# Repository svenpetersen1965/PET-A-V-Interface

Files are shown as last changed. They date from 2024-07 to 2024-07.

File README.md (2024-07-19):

# PET-A-V-Interface
And A/V Interface for Commodore PET computers
This is a <b>preliminary release</b>. The electronics is fully functional, but the test documentation might require some tweaking. 

The prupose of this project is providing video and audio (CB2) outputs for the Commodore PET computers. The non-CRTC machines generate video outputs, which can be mixed to resemble an NTSC video signal. The resulting signal can be displayed with NTSC monitors or suitable video to HDMI converters.

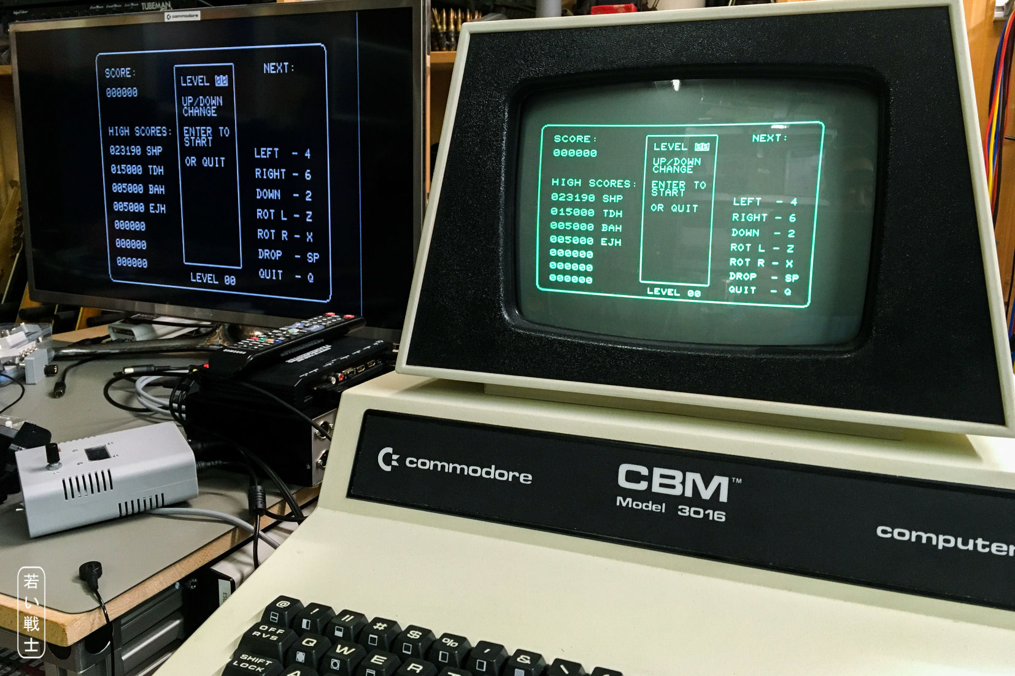
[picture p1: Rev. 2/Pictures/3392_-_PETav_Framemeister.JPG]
CBM3016 with external display


The internal video signal of the CRTC machines is not following any video standards. Thus it requires to modify the CRTC parameters in the EDIT ROM. The disavantage of these modiied settings is, that the internal monitor does not synchronize with them. It is mandatory to disconnect the video and the supply voltage for the monitor if run with PAL or NTSC parameters for more than just a few minutes.

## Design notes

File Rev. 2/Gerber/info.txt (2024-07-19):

      
       Board: PET_AV_Interface
       Rev.:  2
  
       Files:
       ======
  
       All Gerber files are generated in extended gerber format (RS274X)
       *.TOP        : Film top copper
       *.BOT        :  -"- bottom copper
       *.STC        :  -"- top soldermask 
       *.STS        :  -"- bottom soldermask
       *.PLC        :  -"- silk screen top
       *.PLS        :  -"- silk screen bottom 
       *.DK         : Drills plated Through (Excellon)
       *.NDK        : Drills not plated Through (Excellon)
       *.OUT        : Board outline

       Board Size:
       ===========
       Length     :   68.0 mm
       Width      :   56.0 mm
       Thickness  :   1.6 mm
       Material   :   FR 4
       Copper     :   35 um
       Surface    :   HASL
       
       Remarks:
       ========
       Width >= 8mil
       Distance >= 6mil
       Drill >= 0.35mm

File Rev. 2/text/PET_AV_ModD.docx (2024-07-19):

Commodore PET/CBM80xx/40xx A/V-Interface Rev. 2

Module Description

The PET A/V-Interface allows to output composite video and audio signals from the user port of the PET. Non-CRTC machines, like the PET 20xx or CBM30xx are outputting video information, which can be mixed to an NTSC video signal (Figure 5).

CRTC machines, like most CBM40xx and CBM80xx do not follow any video standard, they generate 50 FPS, but the horizontal rates do not fit any video standard. They require a different edit ROM to meet either PAL or NTSC. With this new edit ROM, the built in monitor will not synchronize. It is recommended to switch off the supply voltage of the monitor, while the PAL or NTSC edit ROM is active.

The audio signal is derived from the CB2 output of the User Port, which is widely used to produce audio with PET or CBM machines. The amplitude of the audio signal is approximately 0.6V. The signal is not suitable to directly drive a speaker, an amplifier is required. It is recommended to try out low volume setting first and adjust the volume to taste. Both J7/white and J6/red are identical, since there is no stereo output. It is desirable to connect the audio signal to both stereo channels of the audio/video equipment.

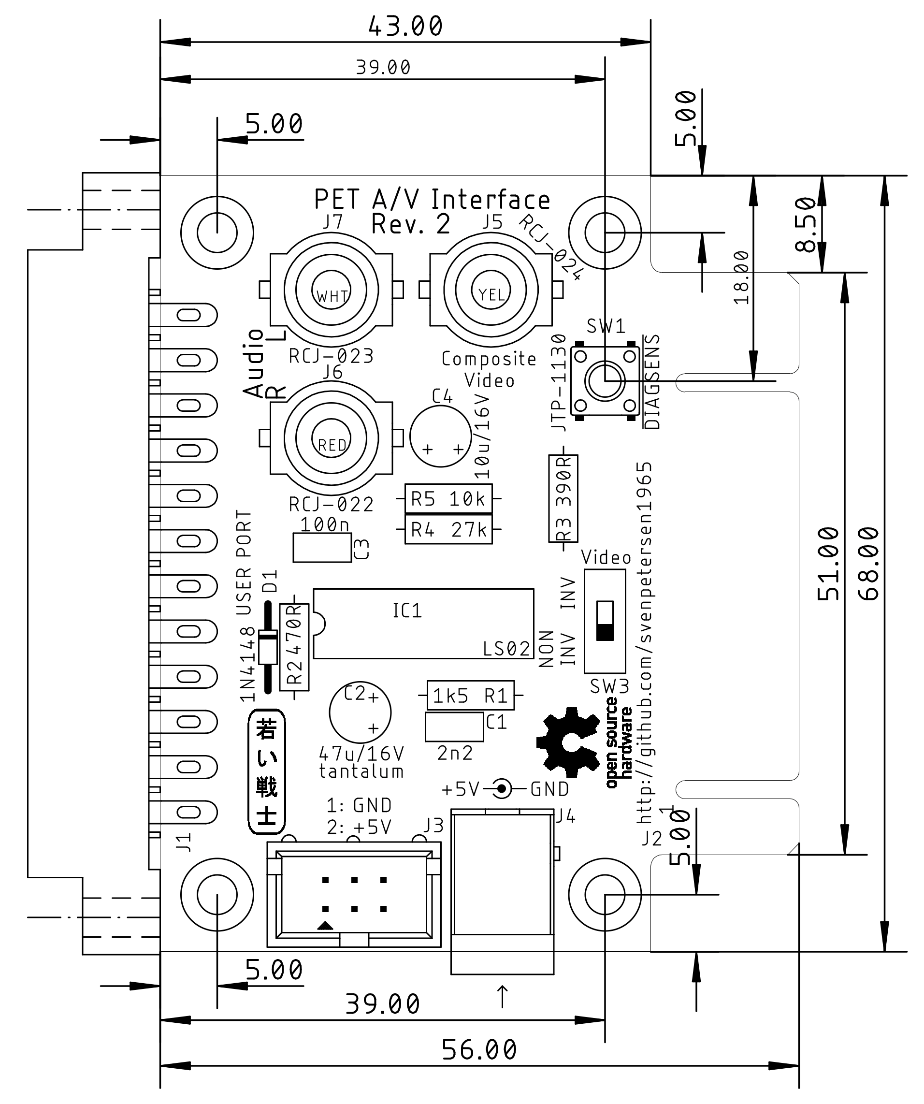
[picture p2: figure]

Figure 1: Dimensions of the PET A/V Interface

The A/V Interface requires a supply voltage of 5V, since the PET user port does not have a +5V pin (like the C64 user port). There are two ways to get 5V to the circuit:

1. Tap the Cassette Port with the Cassette Port dongle of the C64 Diagnostic Harness (which is pass through), a Datassette can still be used.
2. A 5V power supply with a 5.5mm/2.5mm barrel jack (inner lead is +5V).

The User Port of the PET is passed through and can be fully used on the edge connector of the board.

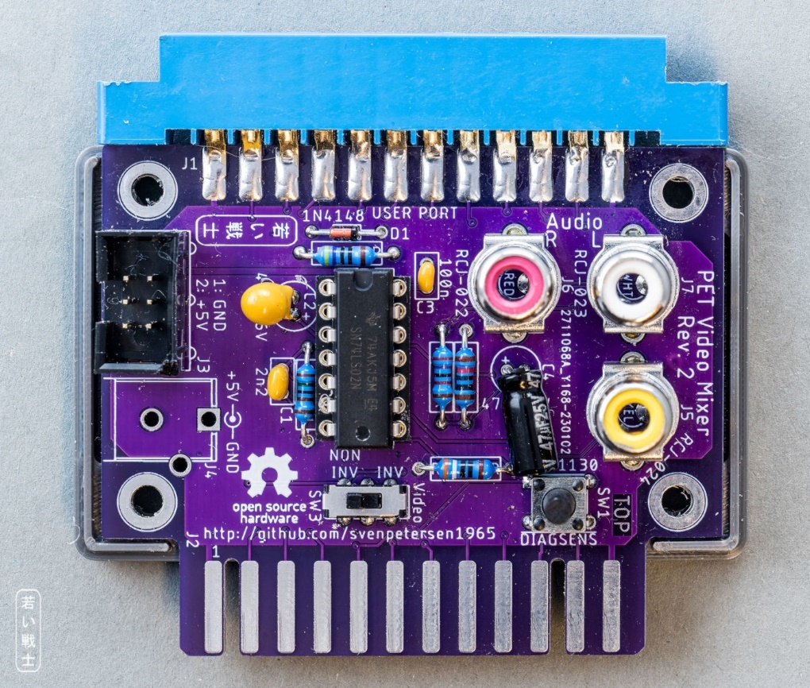
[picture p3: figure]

Figure 2: PET A/V Interface Rev. 2 with power via cassette port/box connector (J3)

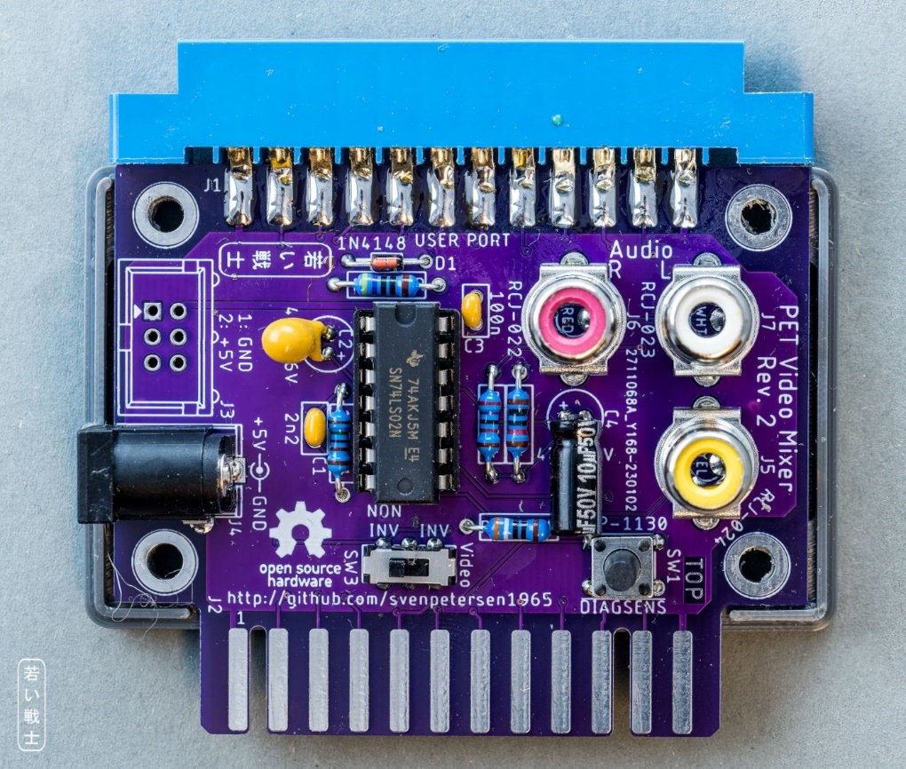
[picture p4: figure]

Figure 3: PET A/V Interface Rev. 2 with barrel connector (J4)

Note: C2 has to be a tantalum capacitor

Note: C4 has to be put flat to fit into the 3D printed case (Figure 2, Figure 3)

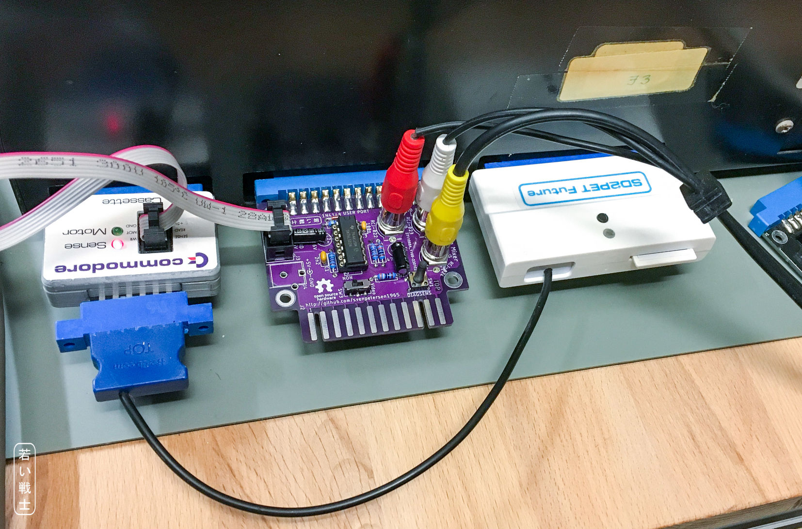
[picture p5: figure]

Figure 4: PET A/V Interface on CBM3016, powered from Cassette port (and SD2PET Future Floppy Disk emulator)


Figure 5: CBM3016 monitor and video output on a Framemeister HDMI adapter

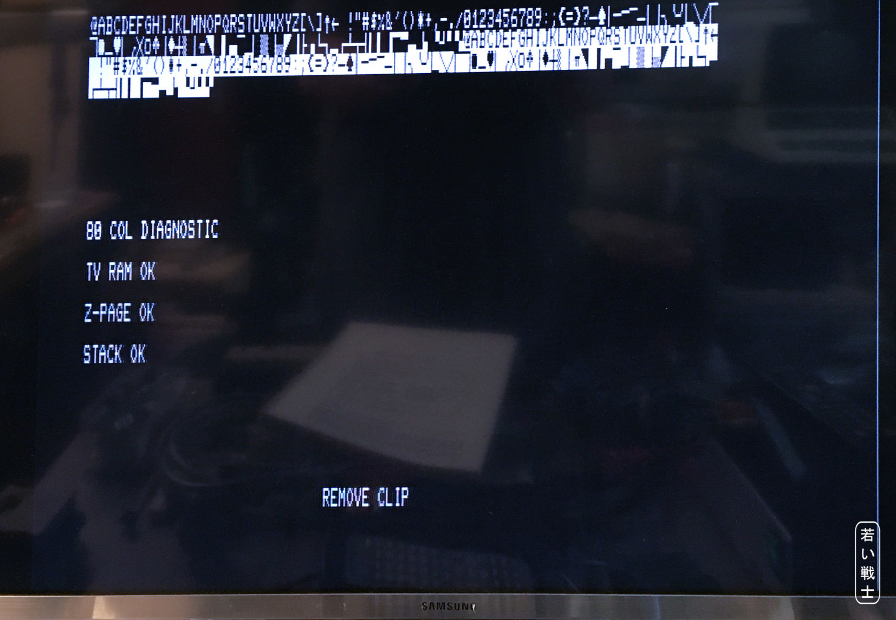
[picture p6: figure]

Figure 6: Output of a CRTC machine with edited parameters for NTSC output (the diagnostic clip software)

The CRTC parameters for an NTSC (60Hz) output were derived from Steve Gray’s Edit ROM (https://github.com/sjgray/cbm-edit-rom/blob/master/crtc-reg-normal.asm) project: https://github.com/sjgray/cbm-edit-rom/blob/master/crtc-reg-normal.asm

Note: It is advised to disconnect and switch off the supply voltage of the CBM 40xx/80xx monitor while operating the mainboard with these modified parameters, since the monitor cannot sync on NTSC. It makes a strange noise instead.

# Connectors

## J1 – PET User Port

2x12 Pin edge connector, 3.96mm pitch

Signal | Pin (top) | Pin (bottom) | Signal
GND | 1 | A | GND
TVVIDEO | 2 | B | CA1
IEEESRQ | 3 | C | PA0
IEEEEOI | 4 | D | PA1
| 5 | E | PA2
TPREAD2 | 6 | F | PA3
TPWRITE | 7 | H | PA4
TPREAD1 | 8 | J | PA5
TVVERT | 9 | K | PA6
TVHOR | 10 | L | PA7
| 11 | M | CB2
GND | 12 | N | GND

## J2 – PET User Port (through)

2x12 Pin board connector, 3.96mm pitch

Signal | Pin (top) | Pin (bottom) | Signal
GND | 1 | A | GND
TVVIDEO | 2 | B | CA1
IEEESRQ | 3 | C | PA0
IEEEEOI | 4 | D | PA1
| 5 | E | PA2
TPREAD2 | 6 | F | PA3
TPWRITE | 7 | H | PA4
TPREAD1 | 8 | J | PA5
TVVERT | 9 | K | PA6
TVHOR | 10 | L | PA7
| 11 | M | CB2
GND | 12 | N | GND

## J3 – Power connector (from cassette port)

2x3 pin box connector

Signal | Pin | Pin | Signal
GND | 1 | 2 | +5V
- | 3 | 4 | -
- | 5 | 6 | -

This connector is optional. It is not required, if the barrel connector J4 is installed.

Powering from cassette port is the preferred way, since it switches off together with the PET. This requires a Cassette Port Dongle (see C64 Diagnostic harness (https://github.com/svenpetersen1965/C64-Diagnostic-Rev.-586220-Harness)).

## J4 - +5VDC Power

5,5mm/2,5mm barrel connector (Cliff FCR681465P)

Pin | Signal
Center | +5VDC
Shaft | GND

This is an alternative power connector, which can be used with an external +5V power supply. It is not the preferred way of powering the module.

## J5, J6, J7 – Audio and Video RCA jacks

3 RCA jacks

Connector | Color | Center | Ring | Type
J5 | Yellow | Composite video | GND | CUI Inc. RCJ-024
J6 | Red | Audio | GND | CUI Inc. RCJ-022
J7 | White | Audio | GND | CUI Inc. RCJ-023

Note: The CUI Inc connectors are pretty wide spread and available from Mouser and Digikey etc. There are acceptable and cheaper connectors from AliExpress, which perfectly fit into the footprint. Click URL (https://de.aliexpress.com/item/1005004200016377.html)

# Switches

## SW1: DIAGSENS

In case SW1 is pushed while power up or reset, the PET boots into the TIM monitor. This might be useful for debugging. The switch is a 6x6mm TACT switch. The appropriate stem height is 13mm, for the 3D printed case.

## SW3: Video non-inverted/inverted

The non CRTC PET models (CBM20xx/30xsx) provide a non-inverted video output on the user port, while the CRTC PET models (like the CBM 40xx or 80xx) provide an inverted signal, which requires to be inverted once more. This can be accomplished with setting SW3.

Model | SW3
PET 20xx | non inverted
CBM 30xx | non inverted
CBM 40xx | inverted
CBM 80xx | inverted

The micro slide switch is a MSS22D18 (through hole, vertical) type, which is widely available from Ali Express. Click URL (https://de.aliexpress.com/item/32955334146.html)

# 3D Printed Case

There are two versions:

- Power supply via box connector J3/cassette port
- Power supply via 5.5mm/2.5mm barrel connector J4/external PSU

The recommended screws are (four) C 2.9x9.5H, DIN 7981 self-tapping screws.

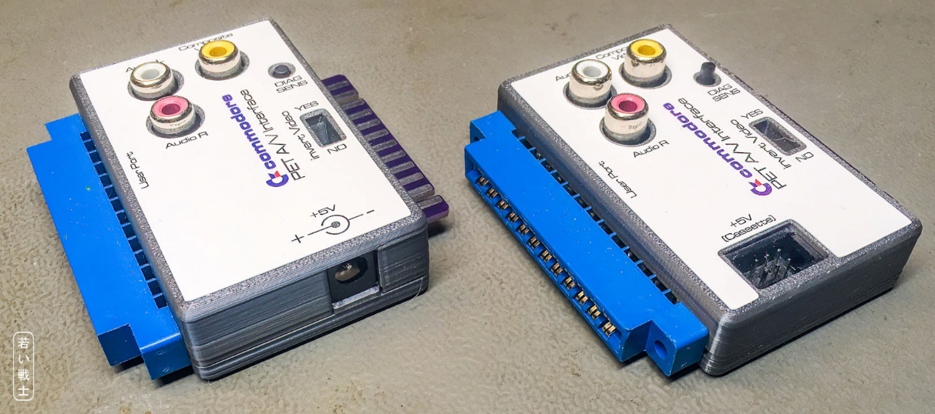
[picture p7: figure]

Figure 7: The two different case types: Barrel connector (left), box connector (right)

# Sources

The basic circuit was derived from the PET Video Mixer by Commodore Pet Users Club of England (Newsletter issues 1 & 2, page 9).

# Revision history

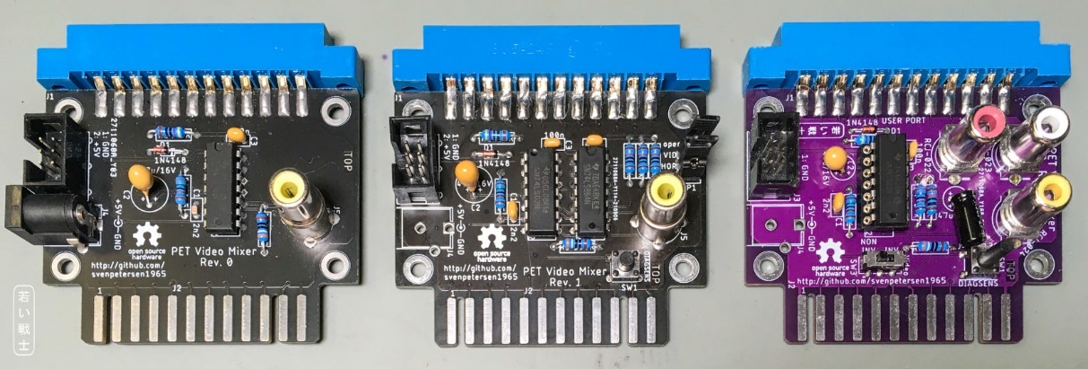
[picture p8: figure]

Figure 8: Rev. 0 (left), Rev. 1 and Rev. 2 (right)

## Rev. 0

- Prototype, original PET Video Mixer circuit with pass through user port and power supply connectors. Working with CBM3016 (and other non CRTC models)

## Rev. 1

- Experimental version: Inverted and non-inverted TVVIDEO, TVVERT and TVHOR signals selectable via jumpers

## Rev. 2

- Renamed to PET-A/V Interface
- Audio outputs added
- TVVIDEO switchable between inverted and non-inverted
- 3D printed case available

PET_AV_ModD.docx 19.07.2024 15:15 Drafted by Sven Petersen Page 2 of 2 Doc.-No.: 167-6-01-02

PET_AV_ModD.docx 19.07.2024 15:15 Drafted by Sven Petersen Page 1 of 1 Doc.-No.: 000-6-00-00

ENZIANWEG 16 ● 83052 BRUCKMÜHL TEL (08062) 728704 ● FAX (08062) 728705

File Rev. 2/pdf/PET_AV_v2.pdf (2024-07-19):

# Project Documentation

## Commodore PET/CBM80xx/40xx A/V-Interface

## Project number: 167

## Revision: 2

## Date: 01.01.2023

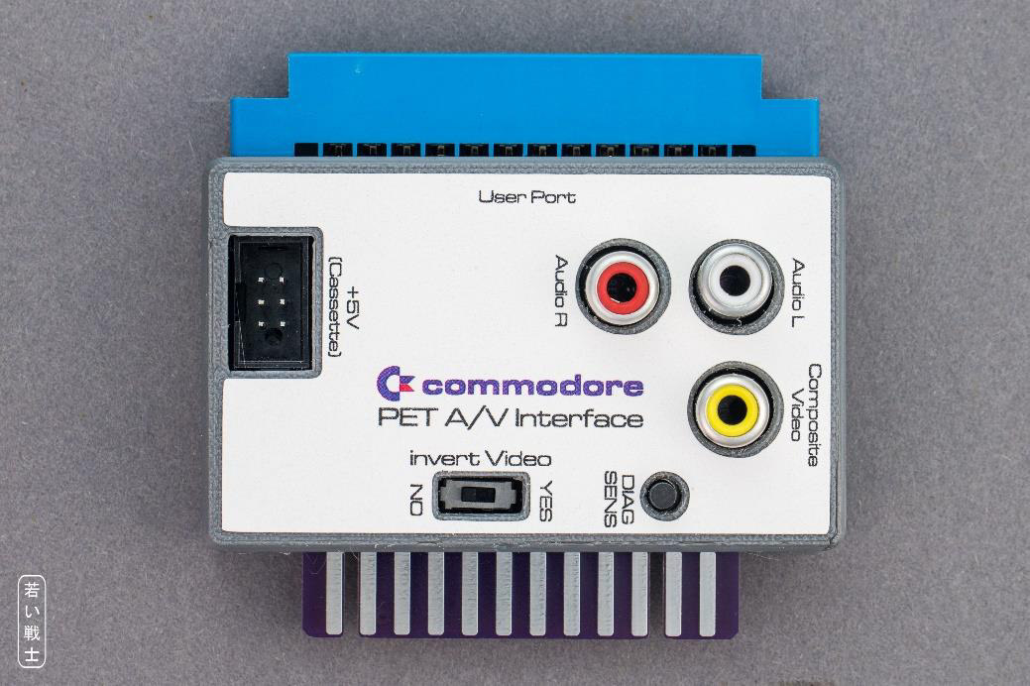
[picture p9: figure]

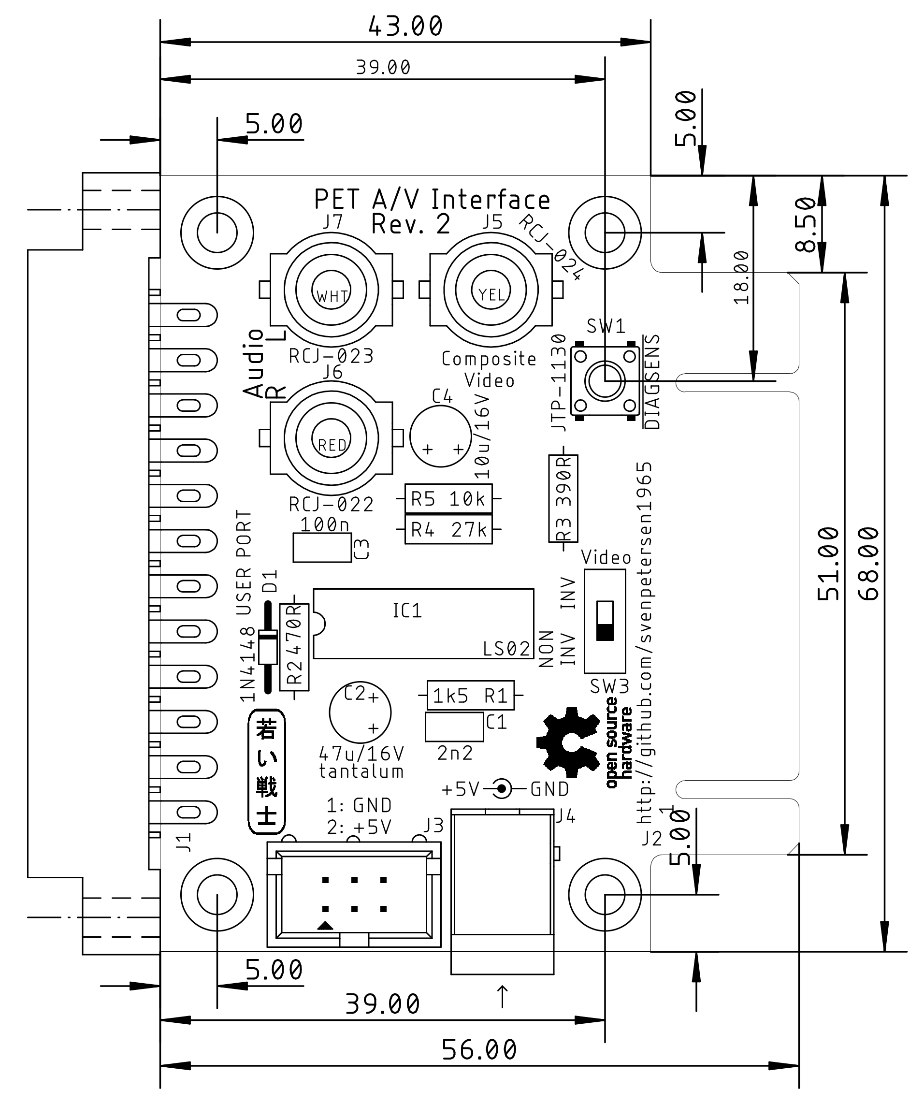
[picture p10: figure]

PET_AV_ModD.docx | | 19.07.2024 15:15
Drafted by Sven Petersen | Page 1 of 8 | Doc.-No.: 167-6-01-02

### Commodore PET/CBM80xx/40xx A/V-Interface Rev. 2

### Module Description

The PET A/V-Interface allows to output composite video and audio signals from the user port of the PET. Non-CRTC machines, like the PET 20xx or CBM30xx are outputting video information, which can be mixed to an NTSC video signal (Figure 5).

CRTC machines, like most CBM40xx and CBM80xx do not follow any video standard, they generate 50 FPS, but the horizontal rates do not fit any video standard. They require a different edit ROM to meet either PAL or NTSC. With this new edit ROM, the built in monitor will not synchronize. It is recommended to switch off the supply voltage of the monitor, while the PAL or NTSC edit ROM is active.

The audio signal is derived from the CB2 output of the User Port, which is widely used to produce audio with PET or CBM machines. The amplitude of the audio signal is approximately 0.6V. The signal is not suitable to directly drive a speaker, an amplifier is required. It is recommended to try out low volume setting first and adjust the volume to taste. Both J7/white and J6/red are identical, since there is no stereo output. It is desirable to connect the audio signal to both stereo channels of the audio/video equipment.

Figure 1: Dimensions of the PET A/V Interface

The A/V Interface requires a supply voltage of 5V, since the PET user port does not have a +5V pin (like the C64 user port). There are two ways to get 5V to the circuit:

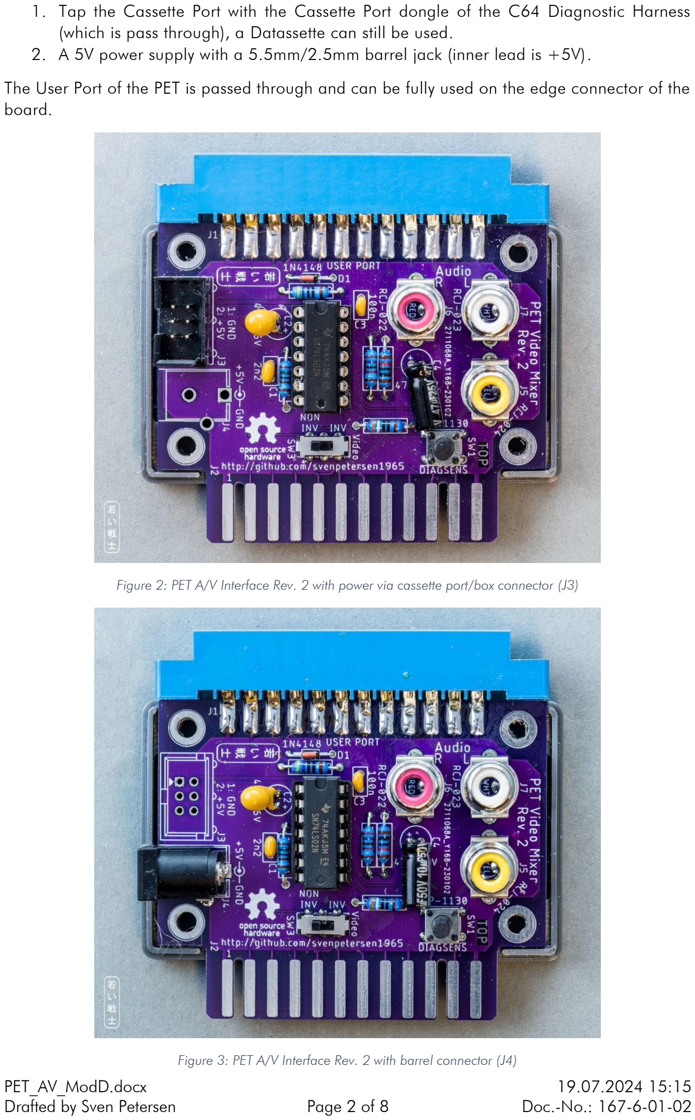
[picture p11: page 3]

PET_AV_ModD.docx | | 19.07.2024 15:15
Drafted by Sven Petersen | Page 2 of 8 | Doc.-No.: 167-6-01-02
1. Tap the Cassette Port with the Cassette Port dongle of the C64 Diagnostic Harness (which is pass through), a Datassette can still be used.
2. A 5V power supply with a 5.5mm/2.5mm barrel jack (inner lead is +5V).

The User Port of the PET is passed through and can be fully used on the edge connector of the board.

Figure 2: PET A/V Interface Rev. 2 with power via cassette port/box connector (J3)

Figure 3: PET A/V Interface Rev. 2 with barrel connector (J4)

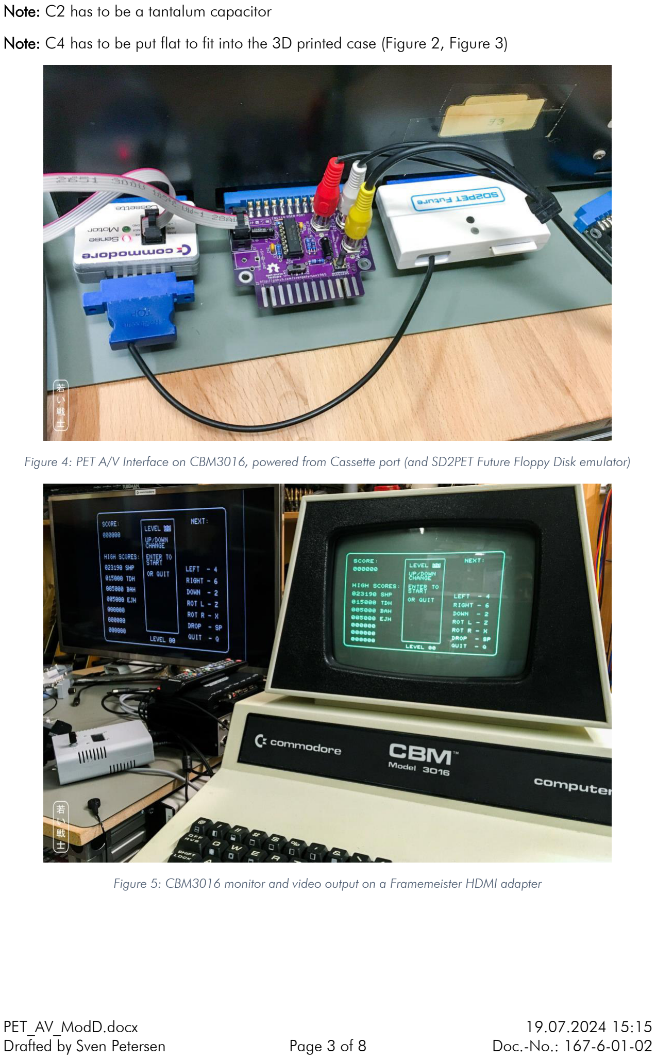
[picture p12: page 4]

PET_AV_ModD.docx | | 19.07.2024 15:15
Drafted by Sven Petersen | Page 3 of 8 | Doc.-No.: 167-6-01-02

Note: C2 has to be a tantalum capacitor

Note: C4 has to be put flat to fit into the 3D printed case (Figure 2, Figure 3)

Figure 4: PET A/V Interface on CBM3016, powered from Cassette port (and SD2PET Future Floppy Disk emulator)

Figure 5: CBM3016 monitor and video output on a Framemeister HDMI adapter

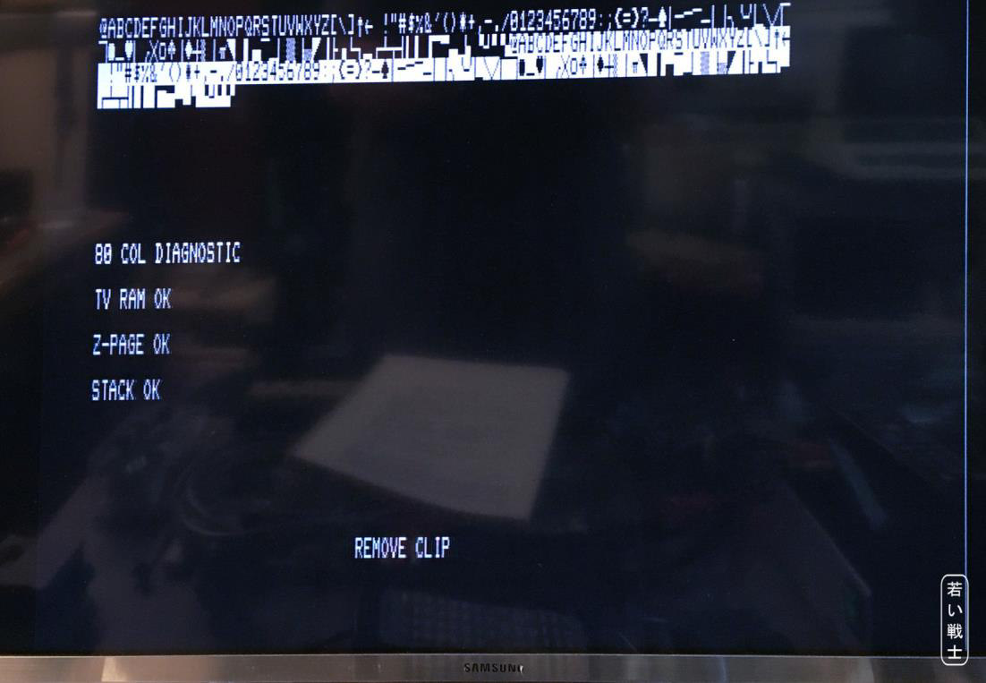
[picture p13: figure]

PET_AV_ModD.docx | | 19.07.2024 15:15
Drafted by Sven Petersen | Page 4 of 8 | Doc.-No.: 167-6-01-02

Figure 6: Output of a CRTC machine with edited parameters for NTSC output (the diagnostic clip software)
The CRTC parameters for an NTSC (60Hz) output were derived from Steve Gray’s Edit ROM (https://github.com/sjgray/cbm-edit-rom/blob/master/crtc-reg-normal.asm) project:
https://github.com/sjgray/cbm-edit-rom/blob/master/crtc-reg-normal.asm

Note: It is advised to disconnect and switch off the supply voltage of the CBM 40xx/80xx monitor while operating the mainboard with these modified parameters, since the monitor cannot sync on NTSC. It makes a strange noise instead.

PET_AV_ModD.docx | | 19.07.2024 15:15
Drafted by Sven Petersen | Page 5 of 8 | Doc.-No.: 167-6-01-02

## Connectors

### J1 – PET User Port

2x12 Pin edge connector, 3.96mm pitch

Signal Pin (top) | Pin (bottom) Signal
GND | 1 | A | GND
TVVIDEO | 2 | B | CA1
IEEESRQ | 3 | C | PA0
IEEEEOI | 4 | D | PA1
DIAGSENSE | 5 | E | PA2
TPREAD2 | 6 | F | PA3
TPWRITE | 7 | H | PA4
TPREAD1 | 8 | J | PA5
TVVERT | 9 | K | PA6
TVHOR | 10 | L | PA7
GRAPHIC | 11 | M | CB2
GND | 12 | N | GND

### J2 – PET User Port (through)

2x12 Pin board connector, 3.96mm pitch

Signal Pin (top) | Pin (bottom) Signal
GND | 1 | A | GND
TVVIDEO | 2 | B | CA1
IEEESRQ | 3 | C | PA0
IEEEEOI | 4 | D | PA1
DIAGSENSE | 5 | E | PA2
TPREAD2 | 6 | F | PA3
TPWRITE | 7 | H | PA4
TPREAD1 | 8 | J | PA5
TVVERT | 9 | K | PA6
TVHOR | 10 | L | PA7
GRAPHIC | 11 | M | CB2
GND | 12 | N | GND

PET_AV_ModD.docx | | 19.07.2024 15:15
Drafted by Sven Petersen | Page 6 of 8 | Doc.-No.: 167-6-01-02

### J3 – Power connector (from cassette port)

2x3 pin box connector

Signal Pin | Pin Signal
GND | 1 | 2 | +5V
- | 3 | 4 | -
- | 5 | 6 | -
This connector is optional. It is not required, if the barrel connector J4 is installed.

Powering from cassette port is the preferred way, since it switches off together with the PET. This requires a Cassette Port Dongle (see C64 Diagnostic harness). (https://github.com/svenpetersen1965/C64-Diagnostic-Rev.-586220-Harness)

### J4 - +5VDC Power

5,5mm/2,5mm barrel connector (Cliff FCR681465P)

Pin | Signal
Center | +5VDC
Shaft | GND
This is an alternative power connector, which can be used with an external +5V power supply. It is not the preferred way of powering the module.

### J5, J6, J7 – Audio and Video RCA jacks

3 RCA jacks

Connector | Color | Center | Ring | Type
J5 | Yellow | Composite video | GND | CUI Inc. RCJ-024
J6 | Red | Audio | GND | CUI Inc. RCJ-022
J7 | White | Audio | GND | CUI Inc. RCJ-023

Note: The CUI Inc connectors are pretty wide spread and available from Mouser and Digikey etc. There are acceptable and cheaper connectors from AliExpress, which perfectly fit into the footprint. Click URL (https://de.aliexpress.com/item/1005004200016377.html)

## Switches

### SW1: DIAGSENS

In case SW1 is pushed while power up or reset, the PET boots into the TIM monitor. This might be useful for debugging. The switch is a 6x6mm TACT switch. The appropriate stem height is 13mm, for the 3D printed case.

### SW3: Video non-inverted/inverted

The non CRTC PET models (CBM20xx/30xsx) provide a non-inverted video output on the user port, while the CRTC PET models (like the CBM 40xx or 80xx) provide an inverted signal, which requires to be inverted once more. This can be accomplished with setting SW3.

Model | SW3
PET 20xx | non inverted
CBM 30xx | non inverted
CBM 40xx | inverted
CBM 80xx | inverted

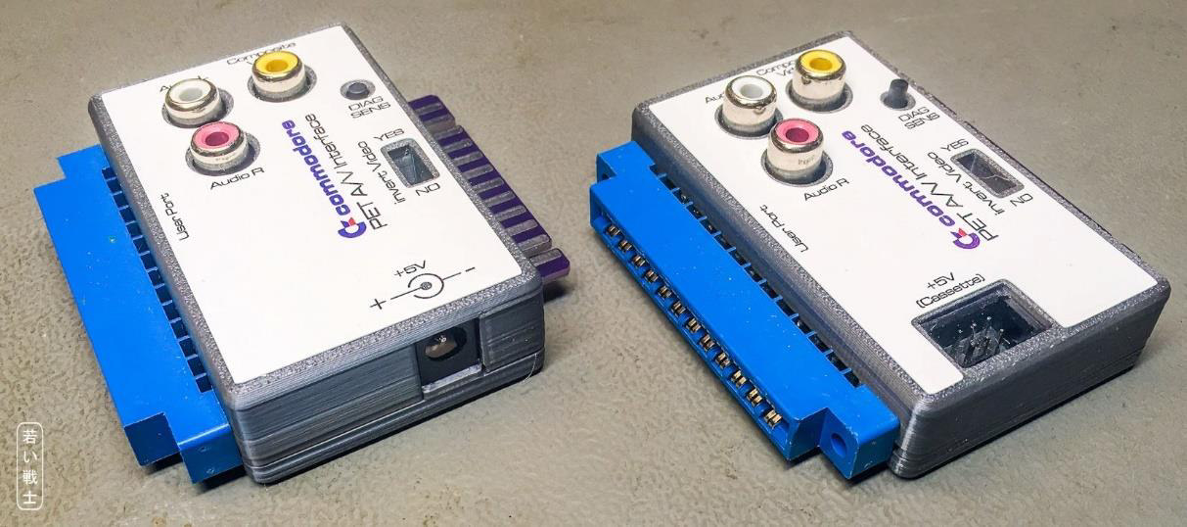
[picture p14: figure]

PET_AV_ModD.docx | | 19.07.2024 15:15
Drafted by Sven Petersen | Page 7 of 8 | Doc.-No.: 167-6-01-02

The micro slide switch is a MSS22D18 (through hole, vertical) type, which is widely available from Ali Express. Click URL (https://de.aliexpress.com/item/32955334146.html)

## 3D Printed Case

There are two versions:

- Power supply via box connector J3/cassette port
- Power supply via 5.5mm/2.5mm barrel connector J4/external PSU

The recommended screws are (four) C 2.9x9.5H, DIN 7981 self-tapping screws.

Figure 7: The two different case types: Barrel connector (left), box connector (right)

## Sources

The basic circuit was derived from the PET Video Mixer by Commodore Pet Users Club of England (Newsletter issues 1 & 2, page 9).

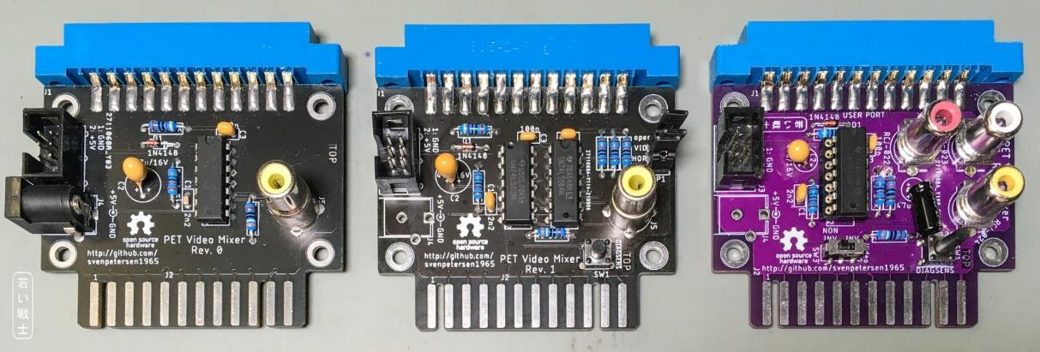
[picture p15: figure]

PET_AV_ModD.docx | | 19.07.2024 15:15
Drafted by Sven Petersen | Page 8 of 8 | Doc.-No.: 167-6-01-02

## Revision history

Figure 8: Rev. 0 (left), Rev. 1 and Rev. 2 (right)

### Rev. 0

- Prototype, original PET Video Mixer circuit with pass through user port and power supply connectors. Working with CBM3016 (and other non CRTC models)

### Rev. 1

- Experimental version: Inverted and non-inverted TVVIDEO, TVVERT and TVHOR signals selectable via jumpers

### Rev. 2

- Renamed to PET-A/V Interface
- Audio outputs added
- TVVIDEO switchable between inverted and non-inverted
- 3D printed case available

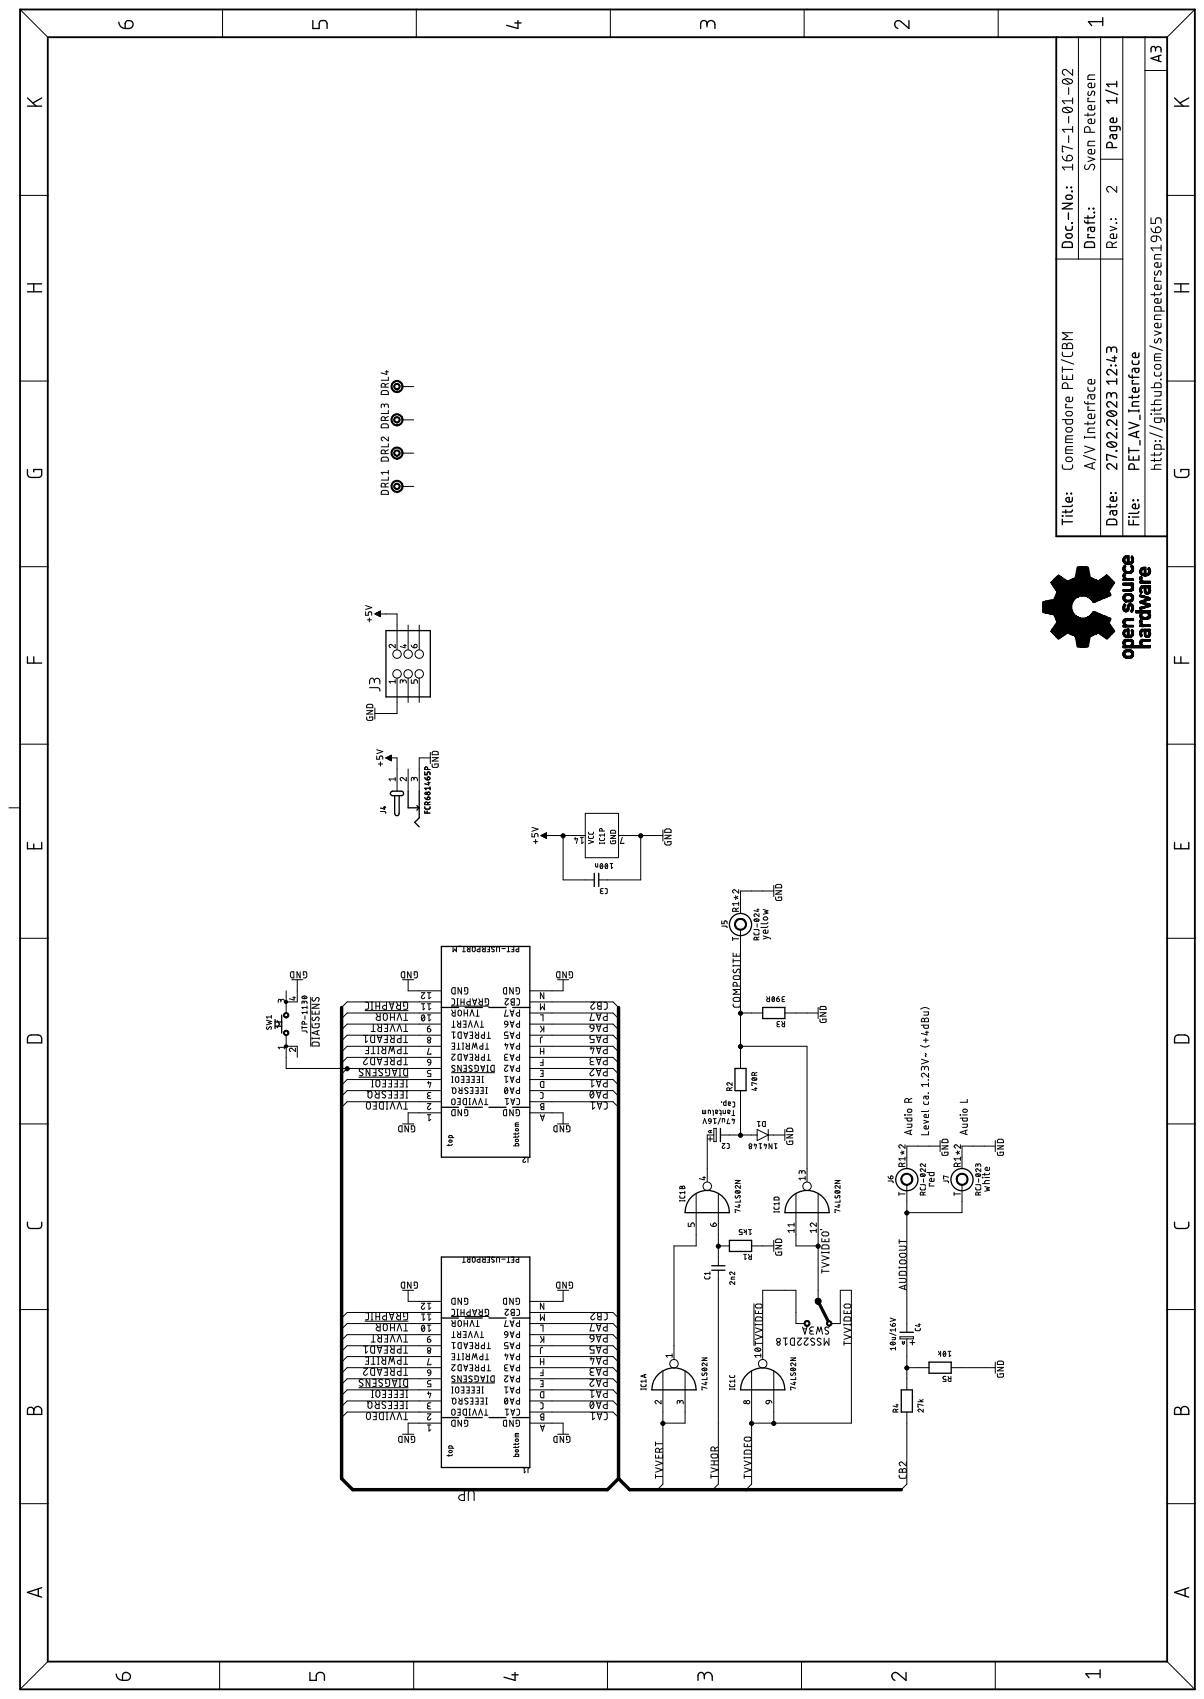
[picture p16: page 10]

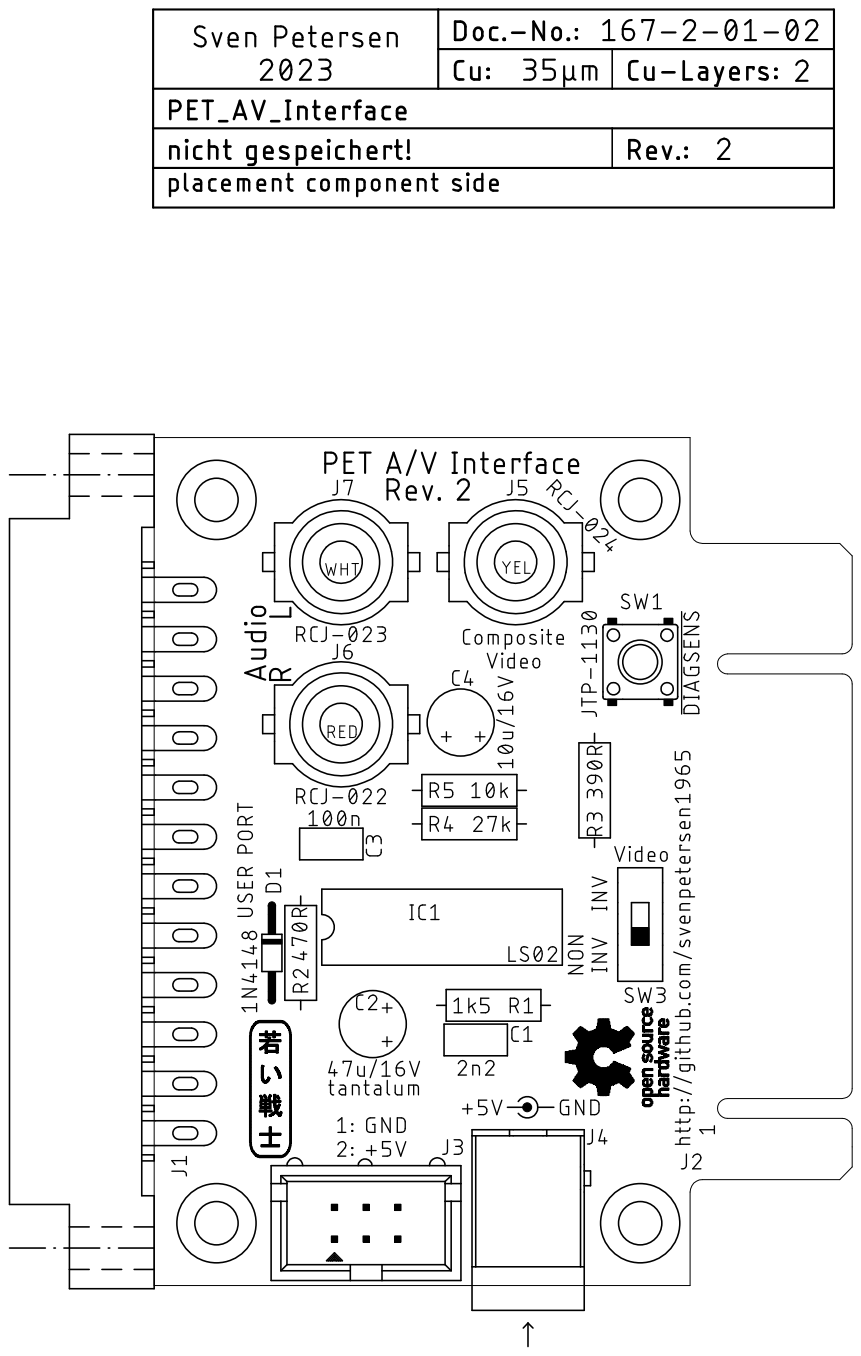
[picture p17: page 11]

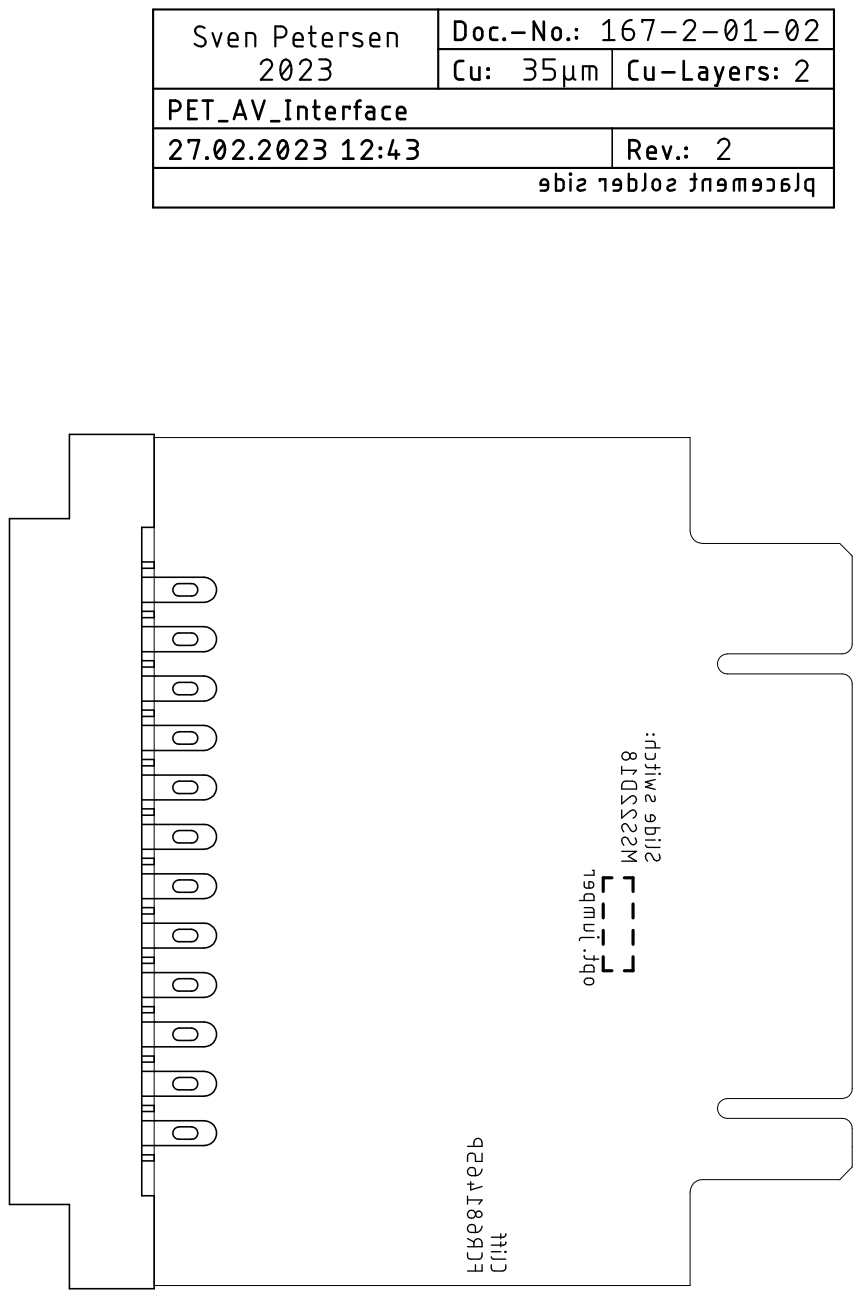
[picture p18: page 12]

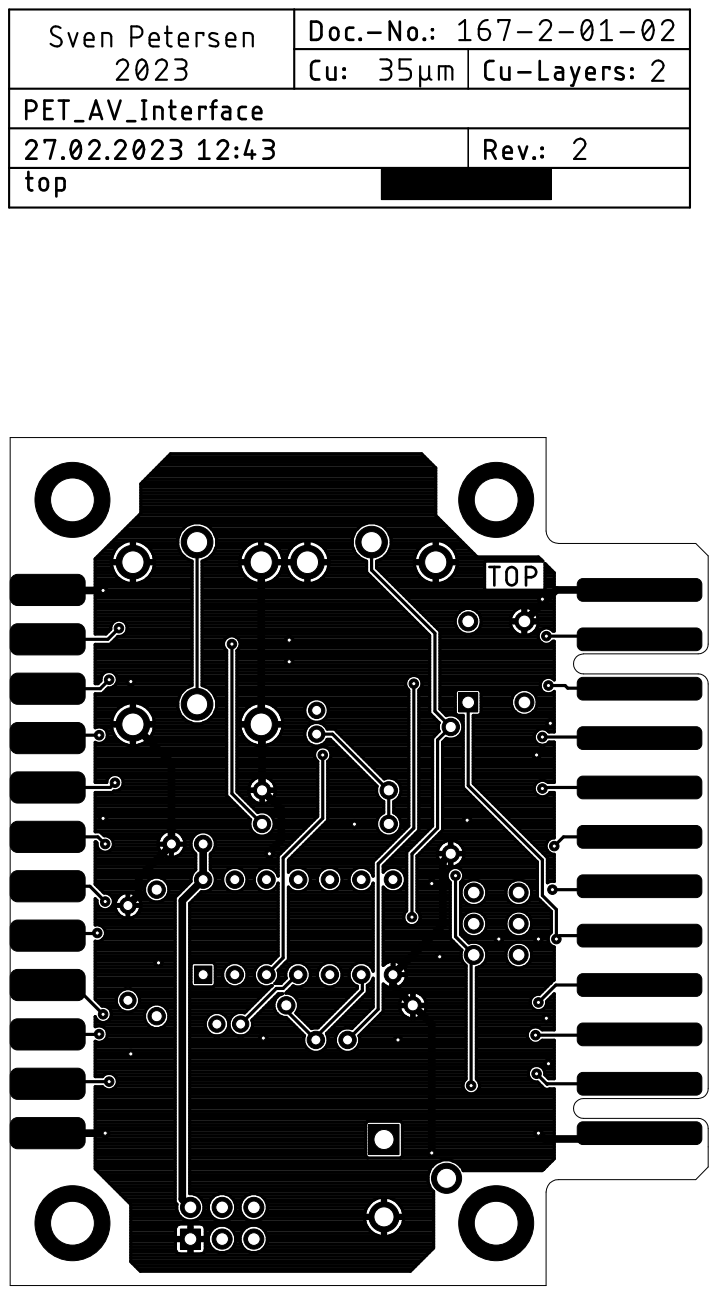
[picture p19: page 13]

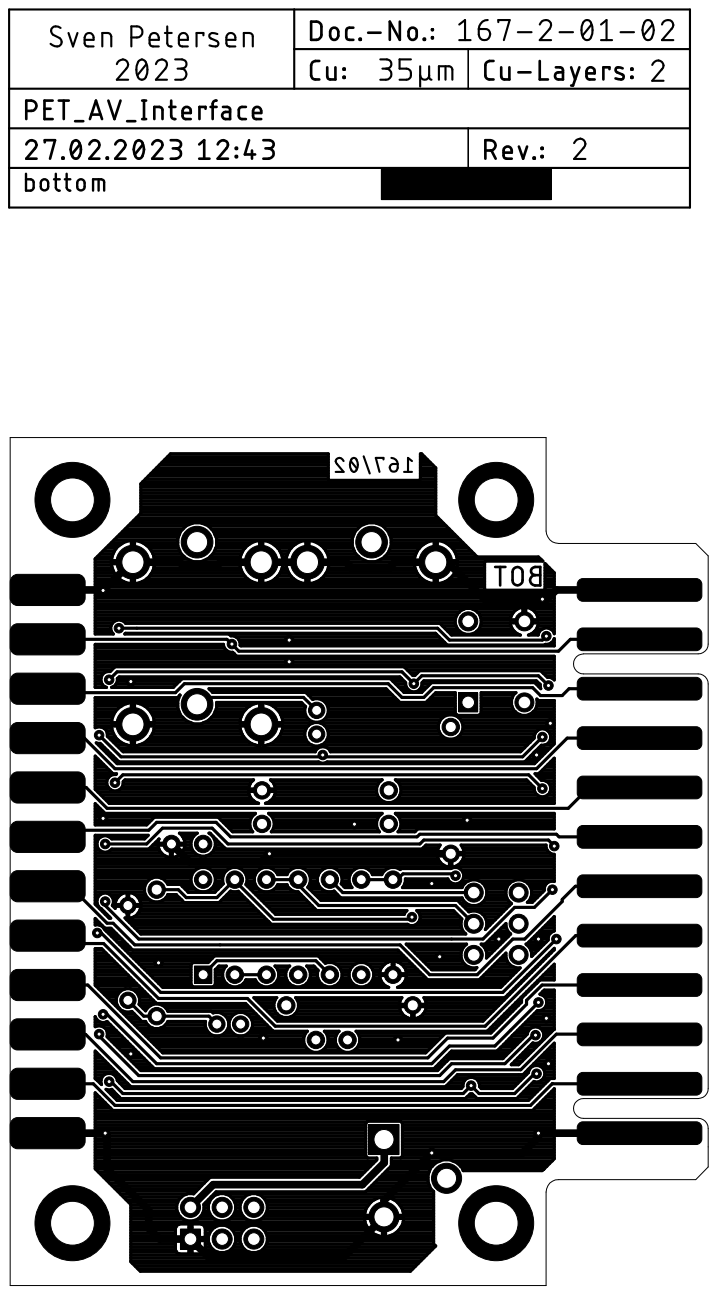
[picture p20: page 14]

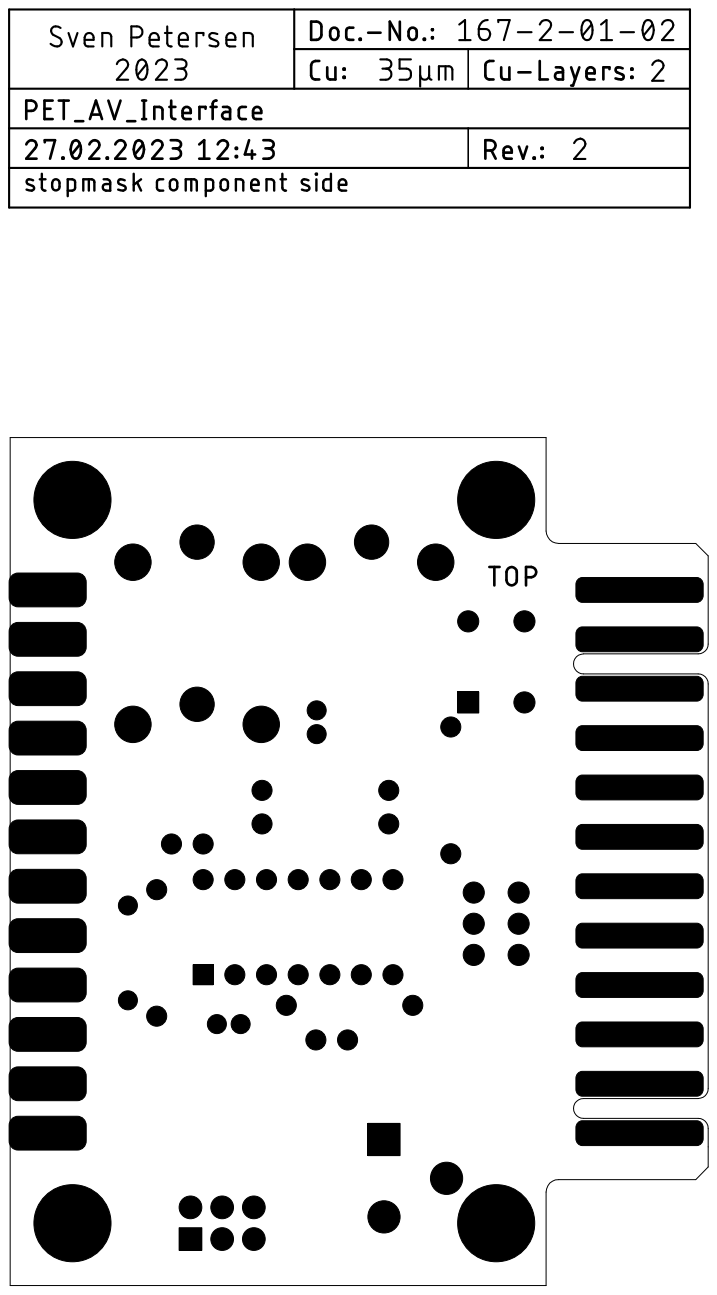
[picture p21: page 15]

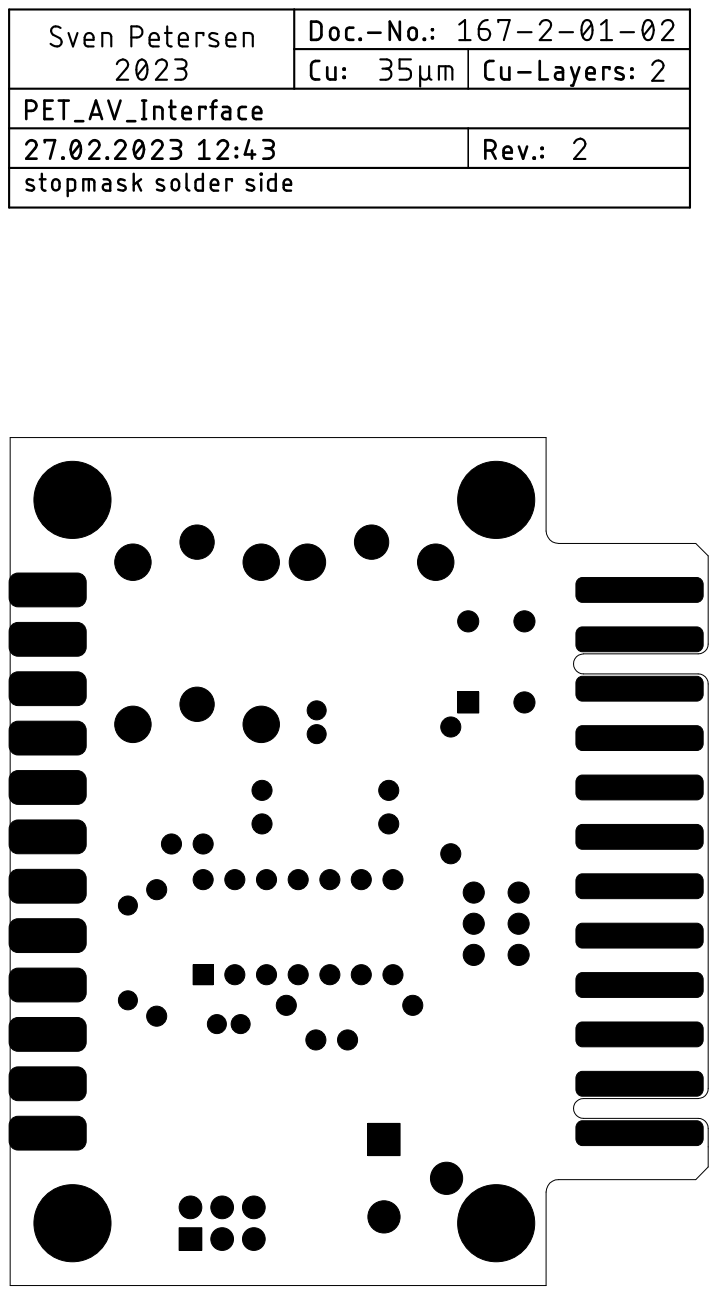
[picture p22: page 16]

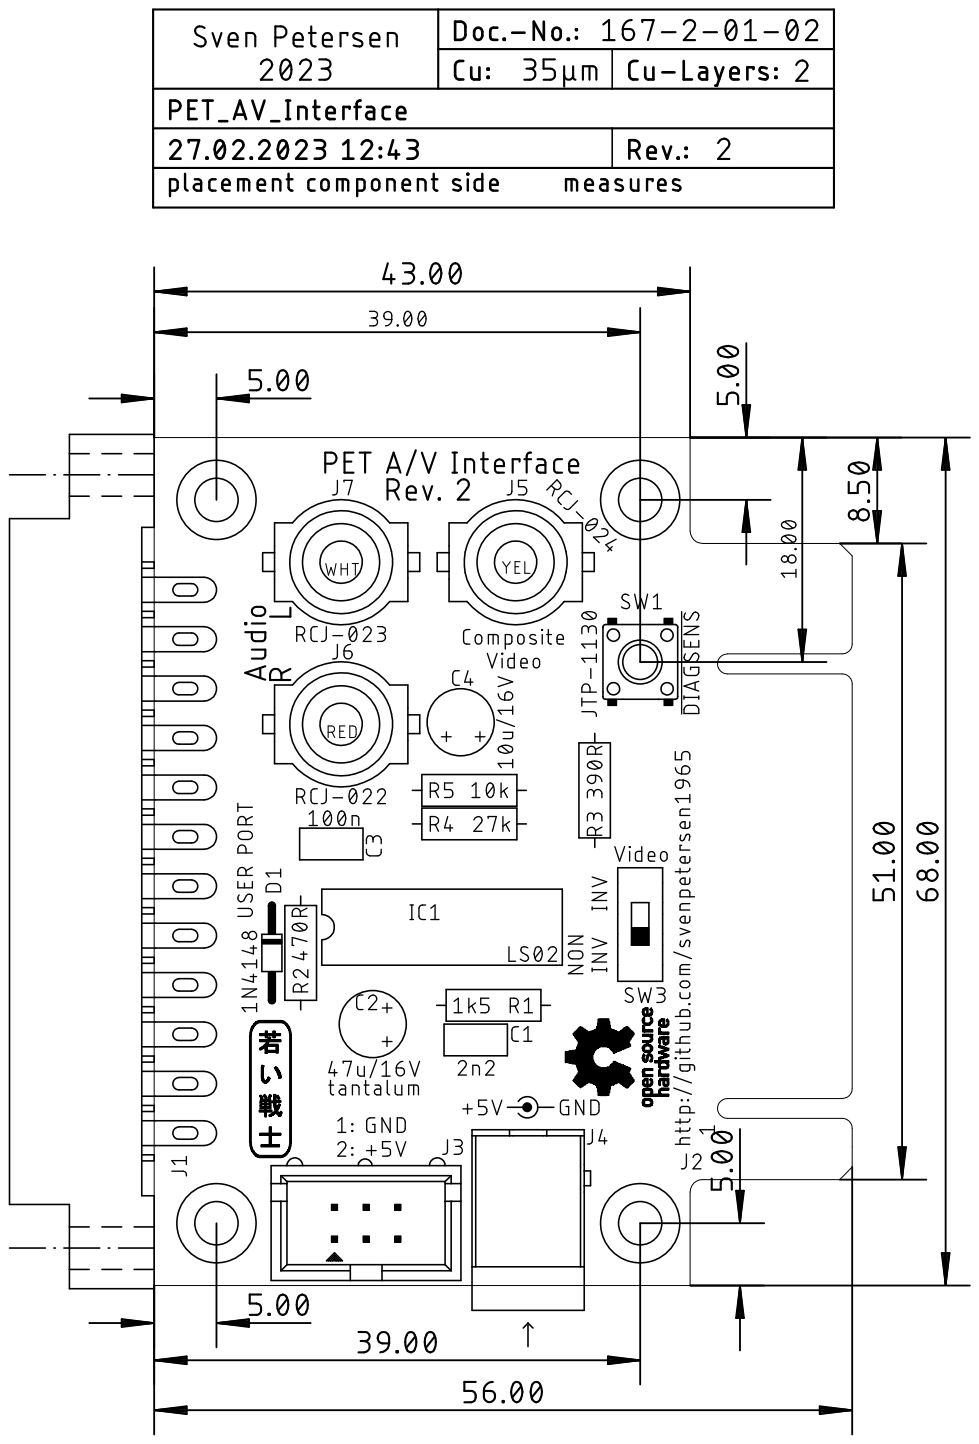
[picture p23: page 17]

PET_AV_Test.docx | | 19.07.2024 15:12
Drafted by Sven Petersen | Page 1 of 4 | Doc.-No.: 167-6-02-02

### Commodore PET/CBM80xx/40xx A/V-Interface Rev. 2

### Testing

## Test Setup

### Computers

- Commodore CBM3016
- Commodore CBM8032

### Video Equipment

- Monitor/Samsung smart TV
- Micomsoft Framemeister XRGB-mini (Video to HDMI converter)
- RetroTINK x2
- TFT display and converter board

### Device Under Test

- PET A/V-Interface Rev. 2, power option: box connector
- Cassette Port Dongle (from C64 Diagnostic Harness) (https://github.com/svenpetersen1965/C64-Diagnostic-Rev.-586220-Harness/tree/master/Diag586220_Harness/Diag586220_Cassette_Port) and ribbon cable.

### Other

- PET Diagnostic Clip (https://github.com/svenpetersen1965/PET-Diagnostic-Clip)
- TFW8bit SD2PET Future (Floppy disk emulator)
- 5m audio/video cable for composite video

## Test Execution

### CBM3016

The PET A/V-Interface was connected to the CBM3016. The Cassette Dongle was and the ribbon cable for providing +5V to the interface was installed. The switch SW3 on the interface is set to “NON INV” (non-inverted).

An A/V cable was used to connect the interface to the Framemeister. The CBM3016 was powered up and the screen content appeared on the monitor.

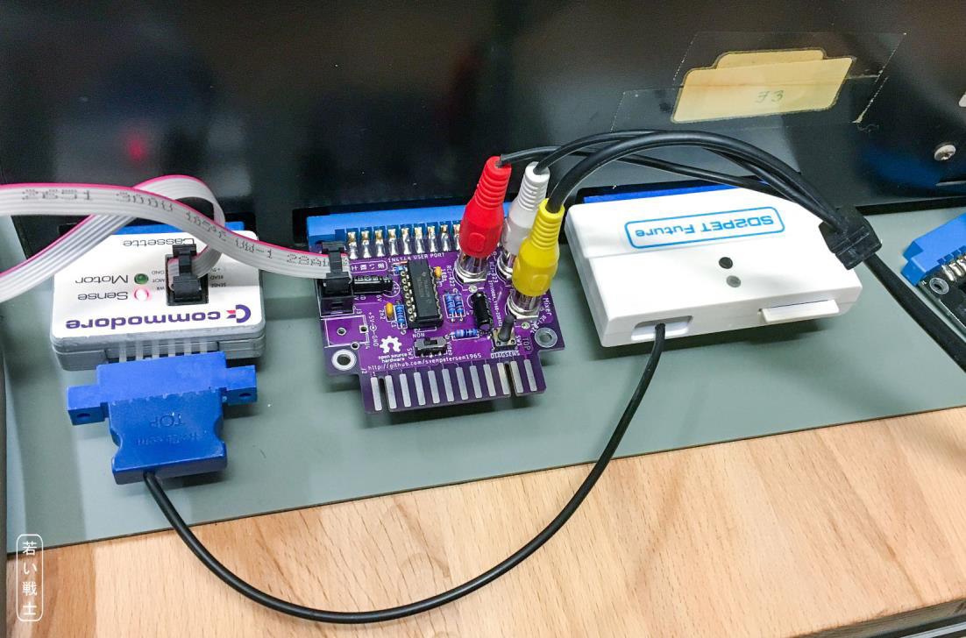
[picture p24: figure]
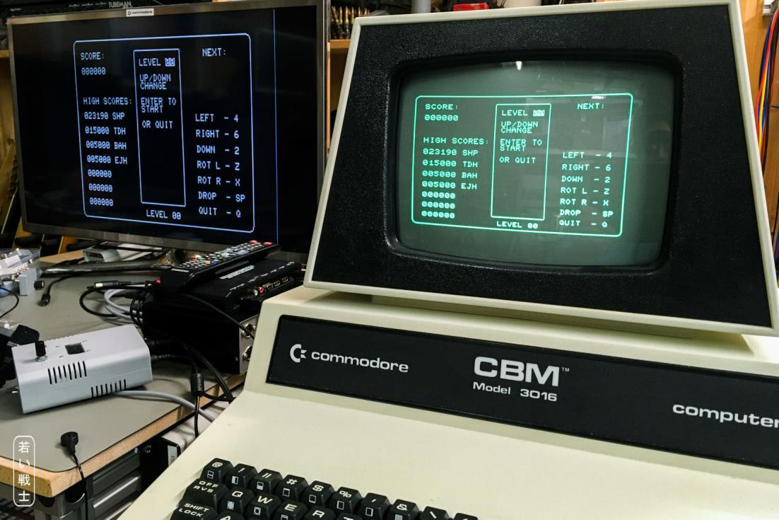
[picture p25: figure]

PET_AV_Test.docx | | 19.07.2024 15:12
Drafted by Sven Petersen | Page 2 of 4 | Doc.-No.: 167-6-02-02

Figure 1: PET A/V Interface on CBM3016, powered from Cassette port (and SD2PET Future Floppy Disk emulator)

Figure 2: CBM3016 monitor and video output on a Framemeister HDMI adapter

A game software was loaded from the SD2PET Future and run. The sounds of the game became audible.

### CBM8032

The switch SW3 was set to “INV” (inverted). To prevent modifying the Edit ROM of the 8032, the 80 col diagnostic software of the Diagnostic Clip (https://github.com/svenpetersen1965/PET-Diagnostic-Clip) was modified. That means, the parameters for an NTSC output of the CRTC were replaced in that software.

$025B $3F $28 $32 $12 $1E $06 $19 $1C $00 $07 $00 $00 $10 $00 $00 $00 $00 $00


PET_AV_Test.docx | | 19.07.2024 15:12
Drafted by Sven Petersen | Page 3 of 4 | Doc.-No.: 167-6-02-02

At the offset address of $025B, the data shown above is replacing the original data. This if the data set labeled “40/80x25, 60 Hz, 15.748 kHz (NTSC) for External Monitor (inverted video)” from Steve Gray’s file “cbm-edit-rom/crtc-reg-normal.asm” (https://github.com/sjgray/cbm-edit-rom/blob/master/crtc-reg-normal.asm)

The BIN-file was burned into an EPROM, which was then installed in the PET Diagnostic Clip. The clip was then installed in the CBM8032. This was then switched on and the Diagnostic Start screen was displayed (Figure 3).

Figure 3: Output of a CRTC machine with edited parameters for NTSC output (the diagnostic clip software)

Note: for completing the Diagnostic Test, the new timing parameters would require to be modified in the test software as well. Without this, the diagnostic test will wail with a horizontal timing error (Figure 4).

Figure 4: Error message of the modified 80col diagnostic software

PET_AV_Test.docx | | 19.07.2024 15:12
Drafted by Sven Petersen | Page 4 of 4 | Doc.-No.: 167-6-02-02

Further, the internal monitor produced an unusual sound and did not sync. It is not recommended to drive the complete with this set of parameters.

## Conclusion

The PET A/V interface works with non CRTC and with CRTC machines.

The required parameter-change for the CRTC machines and the fact, that the internal monitor does not synchronize with the said settings reduces the usability of the A/V interface for this kind of computers to probably only repair purposes.

The PET A/V-Adapter Rev. 2 is fully functional.

Pos. Qty Value Footprint Ref.-No. Comment

1 1 167-2-01-02 2 Layer PCB Rev. 2 2 layer, Cu 35µ, HASL, 43.0mm x 68.0mm, 1.6mm FR4

2 1 2x3 box header, 2.54mm 2X03WV J3 e.g. Reichelt WSL 6G. Option: Power from tape

3 1 100n/50V C-2,5 C3 ceramic capacitor, pitch: 2.5mm

4 1 10k R-10 R5 1/4W, 1% or better

5 1 10u/16V C5,0/2,0 C4 aluminum electrolytic, ∅5.0mm/pitch 2.0mm 105°C, l=11mm, e.G.

Reichelt RD1C106M05011180

6 1 1N4148 DO-35 D1 standard silicon diode
7 1 1k5 R-10 R1 1/4W, 1% or better

8 1 27k R-10 R4 1/4W, 1% or better

9 1 2n2 C-2,5 C1 ceramic capacitor, pitch: 2.5mm

10 1 390R R-10 R3 1/4W, 1% or better

11 1 470R R-10 R2 1/4W, 1% or better

12 1 47u/16V (Tantalum!) C5,0/2,0 C2 tantalum cap!!! E.g. Reichelt TANTAL 47/16

13 1 74LS02N DIL-14 IC1 TI or other

14 1 FCR681465P FCR681465P J4 Cliff. 2,5mm/5.5mm barrel connector. E.g. Reichelt CLIFF FCR681465P
Option: external Power 15 1 JTP-1130 JTP-1130 SW1 standard TACT switch 6mm x 6mm, height = 13mm, e.g. Reichelt JTP-

1130

16 1 MSS22D18 DPDT_9MM SW3 mini slide switch, AliExpress or Amazon. , search term "MSS22D18"

17 1 Edge connector, 2x12,

3.96mm

USERPORT J1 edge connector, C64 user port, Ali Express, "series 805" or other

18 1 RCJ-022 RCJ-02X J6 CUI Inc., RCA jack, vertical, red. Mouser: 490-RCJ-022, Digikey: CP-

1407-ND. Alternative part: Keystone 577

19 1 RCJ-023 RCJ-02X J7 CUI Inc., RCA jack, vertical, white. Mouser: 490-RCJ-023, Digikey: CP-

1408-ND. Alternative part: Keystone 584

20 1 RCJ-024 RCJ-02X J5 CUI Inc., RCA jack, vertical, yellow. Mouser: 490-RCJ-024, Digikey: CP-

1409-ND. Alternative part: Keystone 586

## PET A/V Interface Rev. 2

## Bill of Material Rev. 2.0

PETAV_BOM_2_0.xlsx

Drafted by Sven Petersen Page 1 of 2

19.07.2024 10:17
Doc.No.: 167-5-01-02.0

Pos. Qty Value Footprint Ref.-No. Comment

## PET A/V Interface Rev. 2

## Bill of Material Rev. 2.0

PETAV_BOM_2_0.xlsx

Drafted by Sven Petersen Page 2 of 2

19.07.2024 10:17
Doc.No.: 167-5-01-02.0

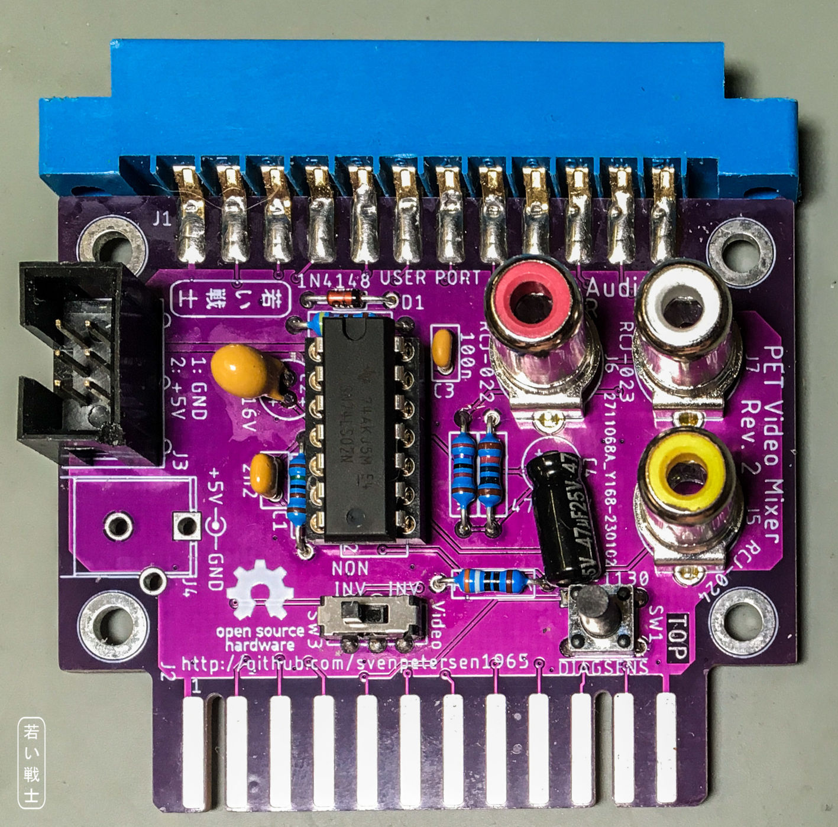
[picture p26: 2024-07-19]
Rev. 2/Pictures/5668_-_PETVid_v2.JPG

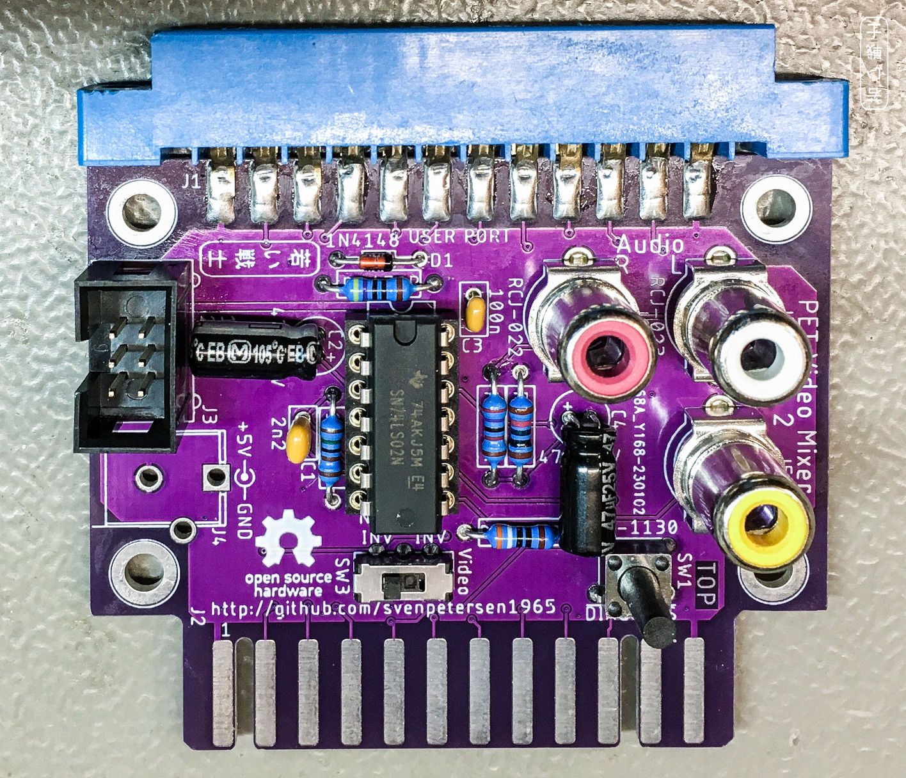
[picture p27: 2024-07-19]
Rev. 2/Pictures/3394_-_PETav_AlEl - Kopie.JPG

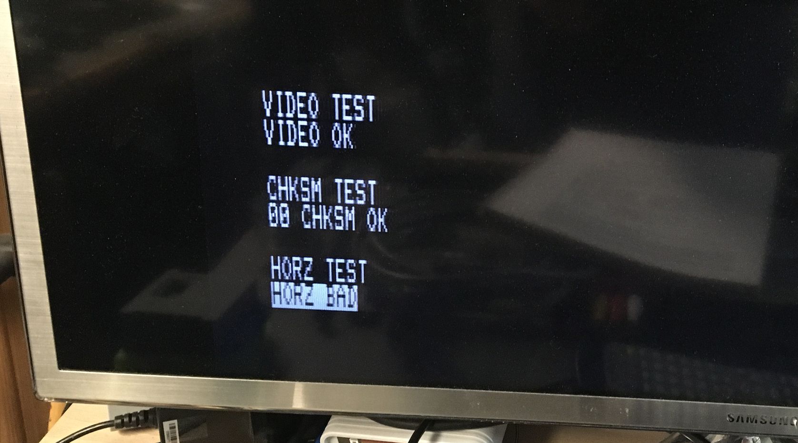
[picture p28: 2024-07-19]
Rev. 2/Pictures/3208_-_8032_Diagnostic_Fail.JPG

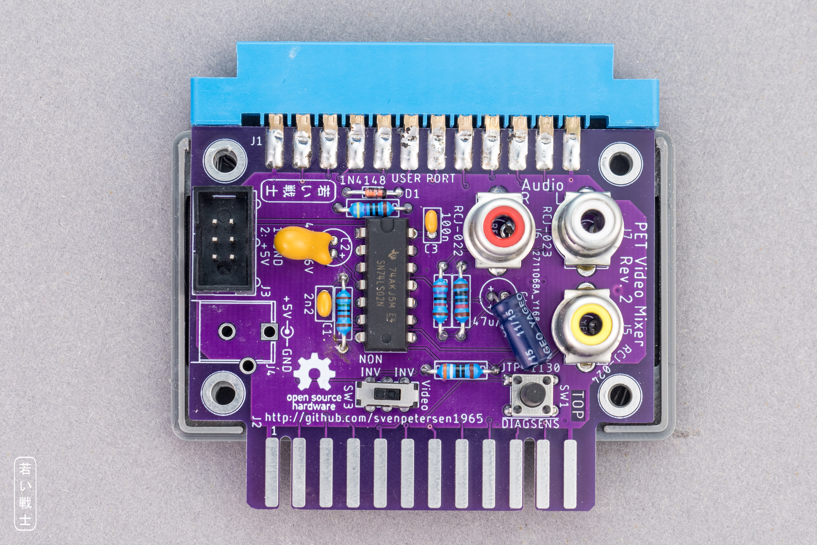
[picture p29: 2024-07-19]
Rev. 2/Pictures/5526_-_PETVid_v2.JPG.JPG

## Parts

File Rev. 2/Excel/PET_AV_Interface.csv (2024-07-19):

Qty | Value | Device | Package | Parts | Description
1 |  | 2X03WV | 2X03WV | J3
4 |  | BOHR3,5 | BOHR3,5 | DRL1, DRL2, DRL3, DRL4
1 | 100n | CAP01 | C-2,5 | C3
1 | 10k | RES04 | R-10 | R5
1 | 10u/16V | C05,0/2,0 | C5,0/2,0 | C4
1 | 1N4148 | 1N41480.3";DO-35/3" | D1
1 | 1k5 | RES04 | R-10 | R1
1 | 27k | RES04 | R-10 | R4
1 | 2n2 | CAP01 | C-2,5 | C1
1 | 390R | RES04 | R-10 | R3
1 | 470R | RES04 | R-10 | R2
1 | 47u/16V | C05,0/2,0 | C5,0/2,0 | C2
1 | 74LS02N | 7402N | DIL-14 | IC1
1 | FCR681465P | FCR681465P | FCR681465P | J4
1 | JTP-1130 | JTP-1130 | JTP-1130 | SW1
1 | MSS22D18 | DPDT_9MM | DPDT_9MM | SW3
1 | OPEN_SOURCE_HW | OPEN_SOURCE_HW | OPENHW | U$2
1 | PET-USERPORT | PET-USERPORT | USERPORT | J1
1 | PET-USERPORT_M | PET-USERPORT_M | USERPORT_M | J2
1 | RCJ-022 | RCJ-02X | RCJ-02X | J6
1 | RCJ-023 | RCJ-02X | RCJ-02X | J7
1 | RCJ-024 | RCJ-02X | RCJ-02X | J5

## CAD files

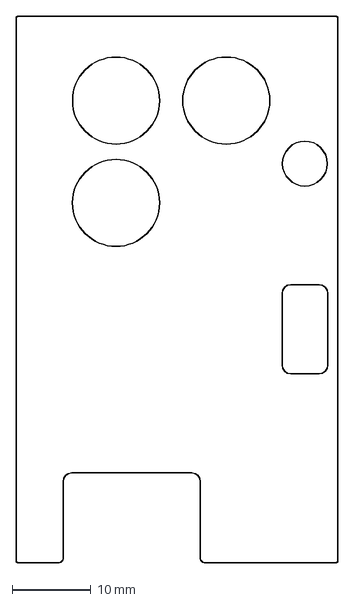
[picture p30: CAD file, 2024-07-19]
Case/Rev2/Label/Label_CPPwr.dxf
40.9 x 69.4 mm

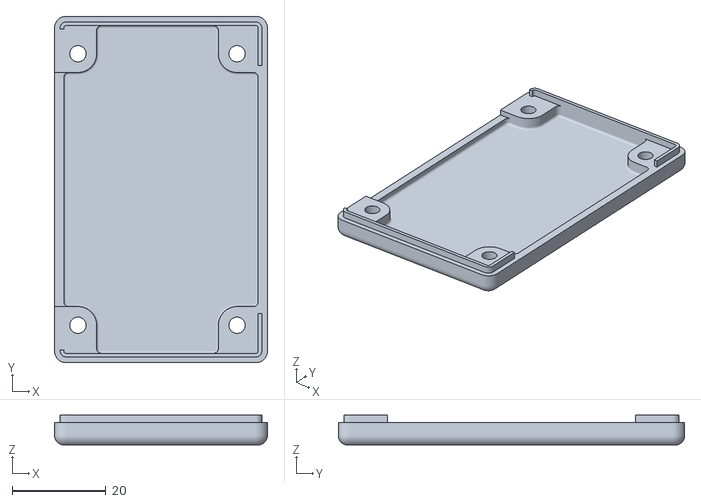
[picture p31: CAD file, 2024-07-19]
Case/Rev2/STL/PET_AV_bottom_shell.stl
45.5 x 74.0 x 6.40

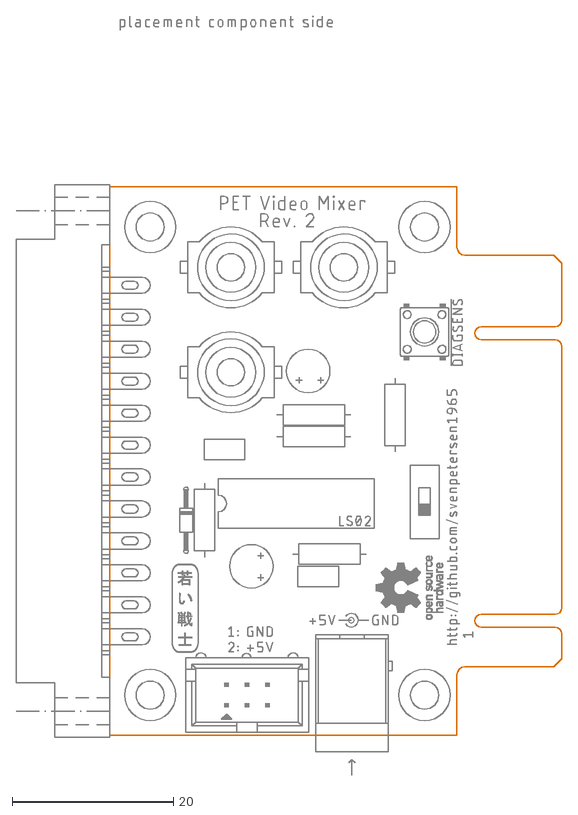
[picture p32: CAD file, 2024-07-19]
Rev. 2/dxf/PET_AV_Interface.dxf
67.6 x 94.0

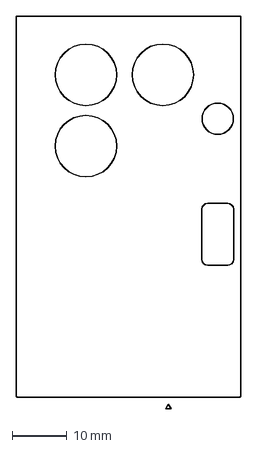
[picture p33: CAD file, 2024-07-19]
Case/Rev2/Label/Label_BarrelPwr.dxf
40.9 x 71.6 mm

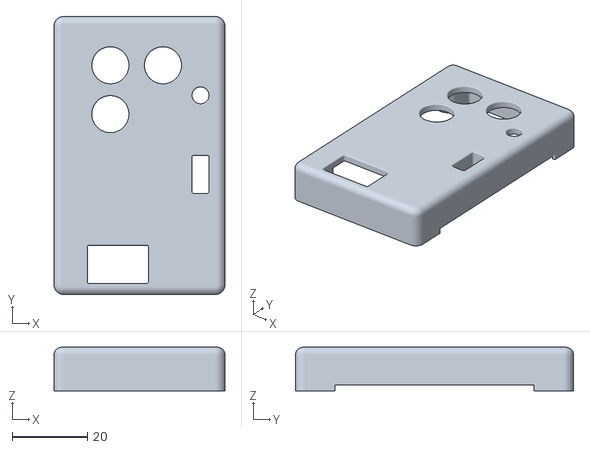
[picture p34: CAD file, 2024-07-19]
Case/Rev2/STL/PET_AV_top_shell.stl
45.5 x 74.0 x 11.6

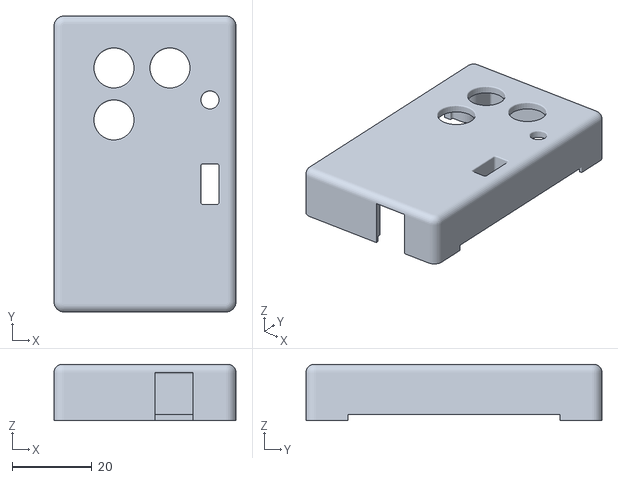
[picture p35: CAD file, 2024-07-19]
Case/Rev2/STL/PET_AV_top_shell_barrel.stl
45.5 x 74.0 x 14.1

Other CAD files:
Case/Rev2/STL/PET_AV_bottom_shell_barrel.stl
Case/Rev2/Fusion360/PET_AV-Interface_rev2 v11.f3d
Case/Rev2/Fusion360/PET_AV-Interface_rev2_barrel v10.f3d

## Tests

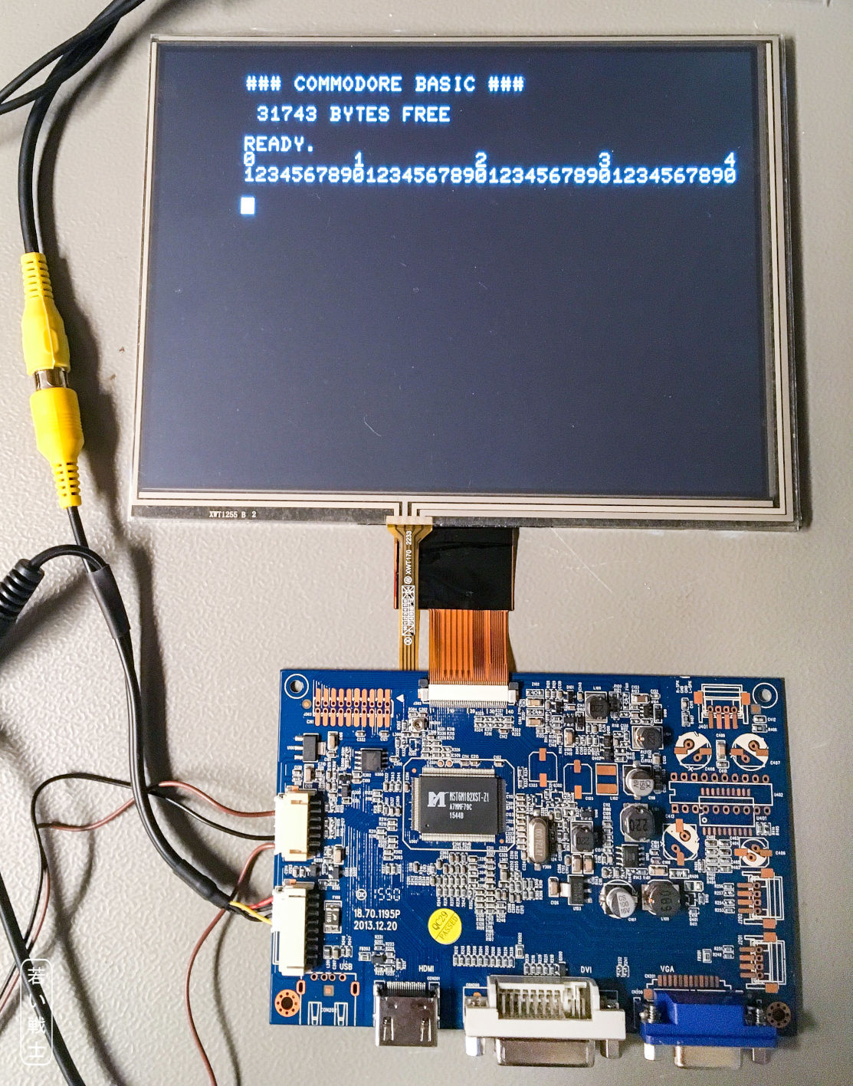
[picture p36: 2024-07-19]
Rev. 2/Pictures/3443_-_PETVid_Test_openFrame_Displ.JPG

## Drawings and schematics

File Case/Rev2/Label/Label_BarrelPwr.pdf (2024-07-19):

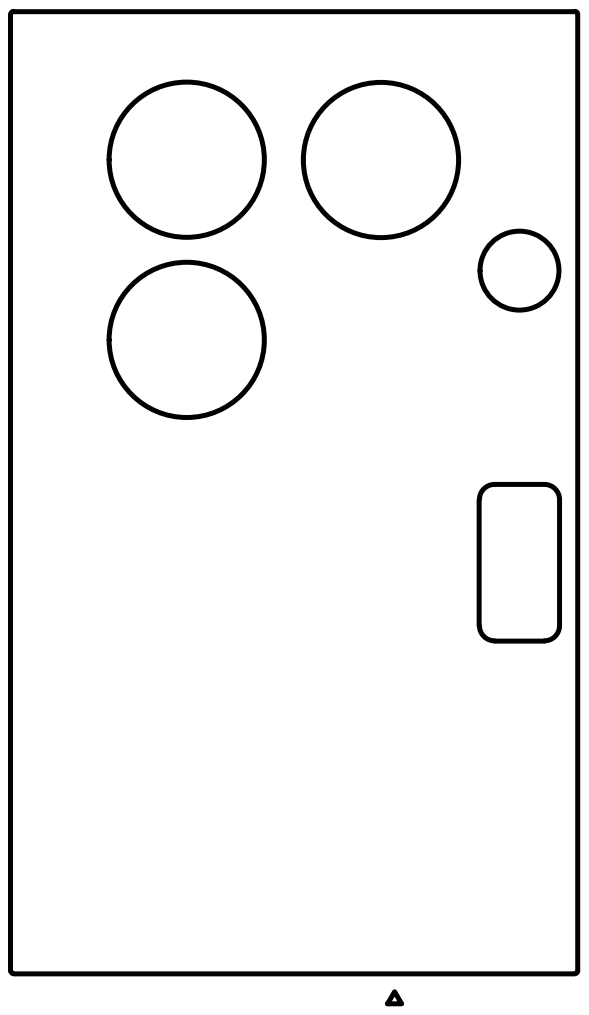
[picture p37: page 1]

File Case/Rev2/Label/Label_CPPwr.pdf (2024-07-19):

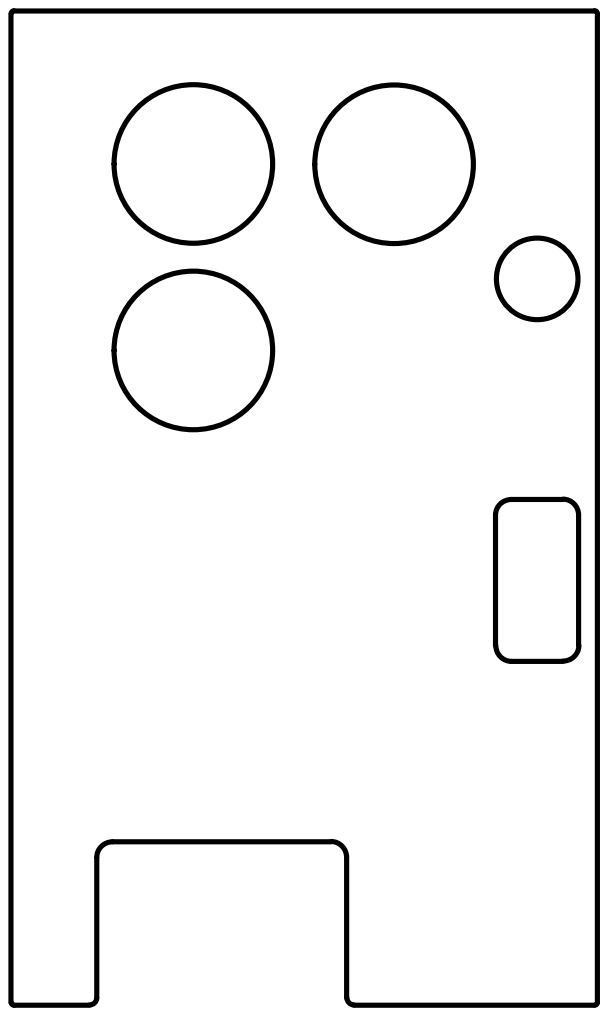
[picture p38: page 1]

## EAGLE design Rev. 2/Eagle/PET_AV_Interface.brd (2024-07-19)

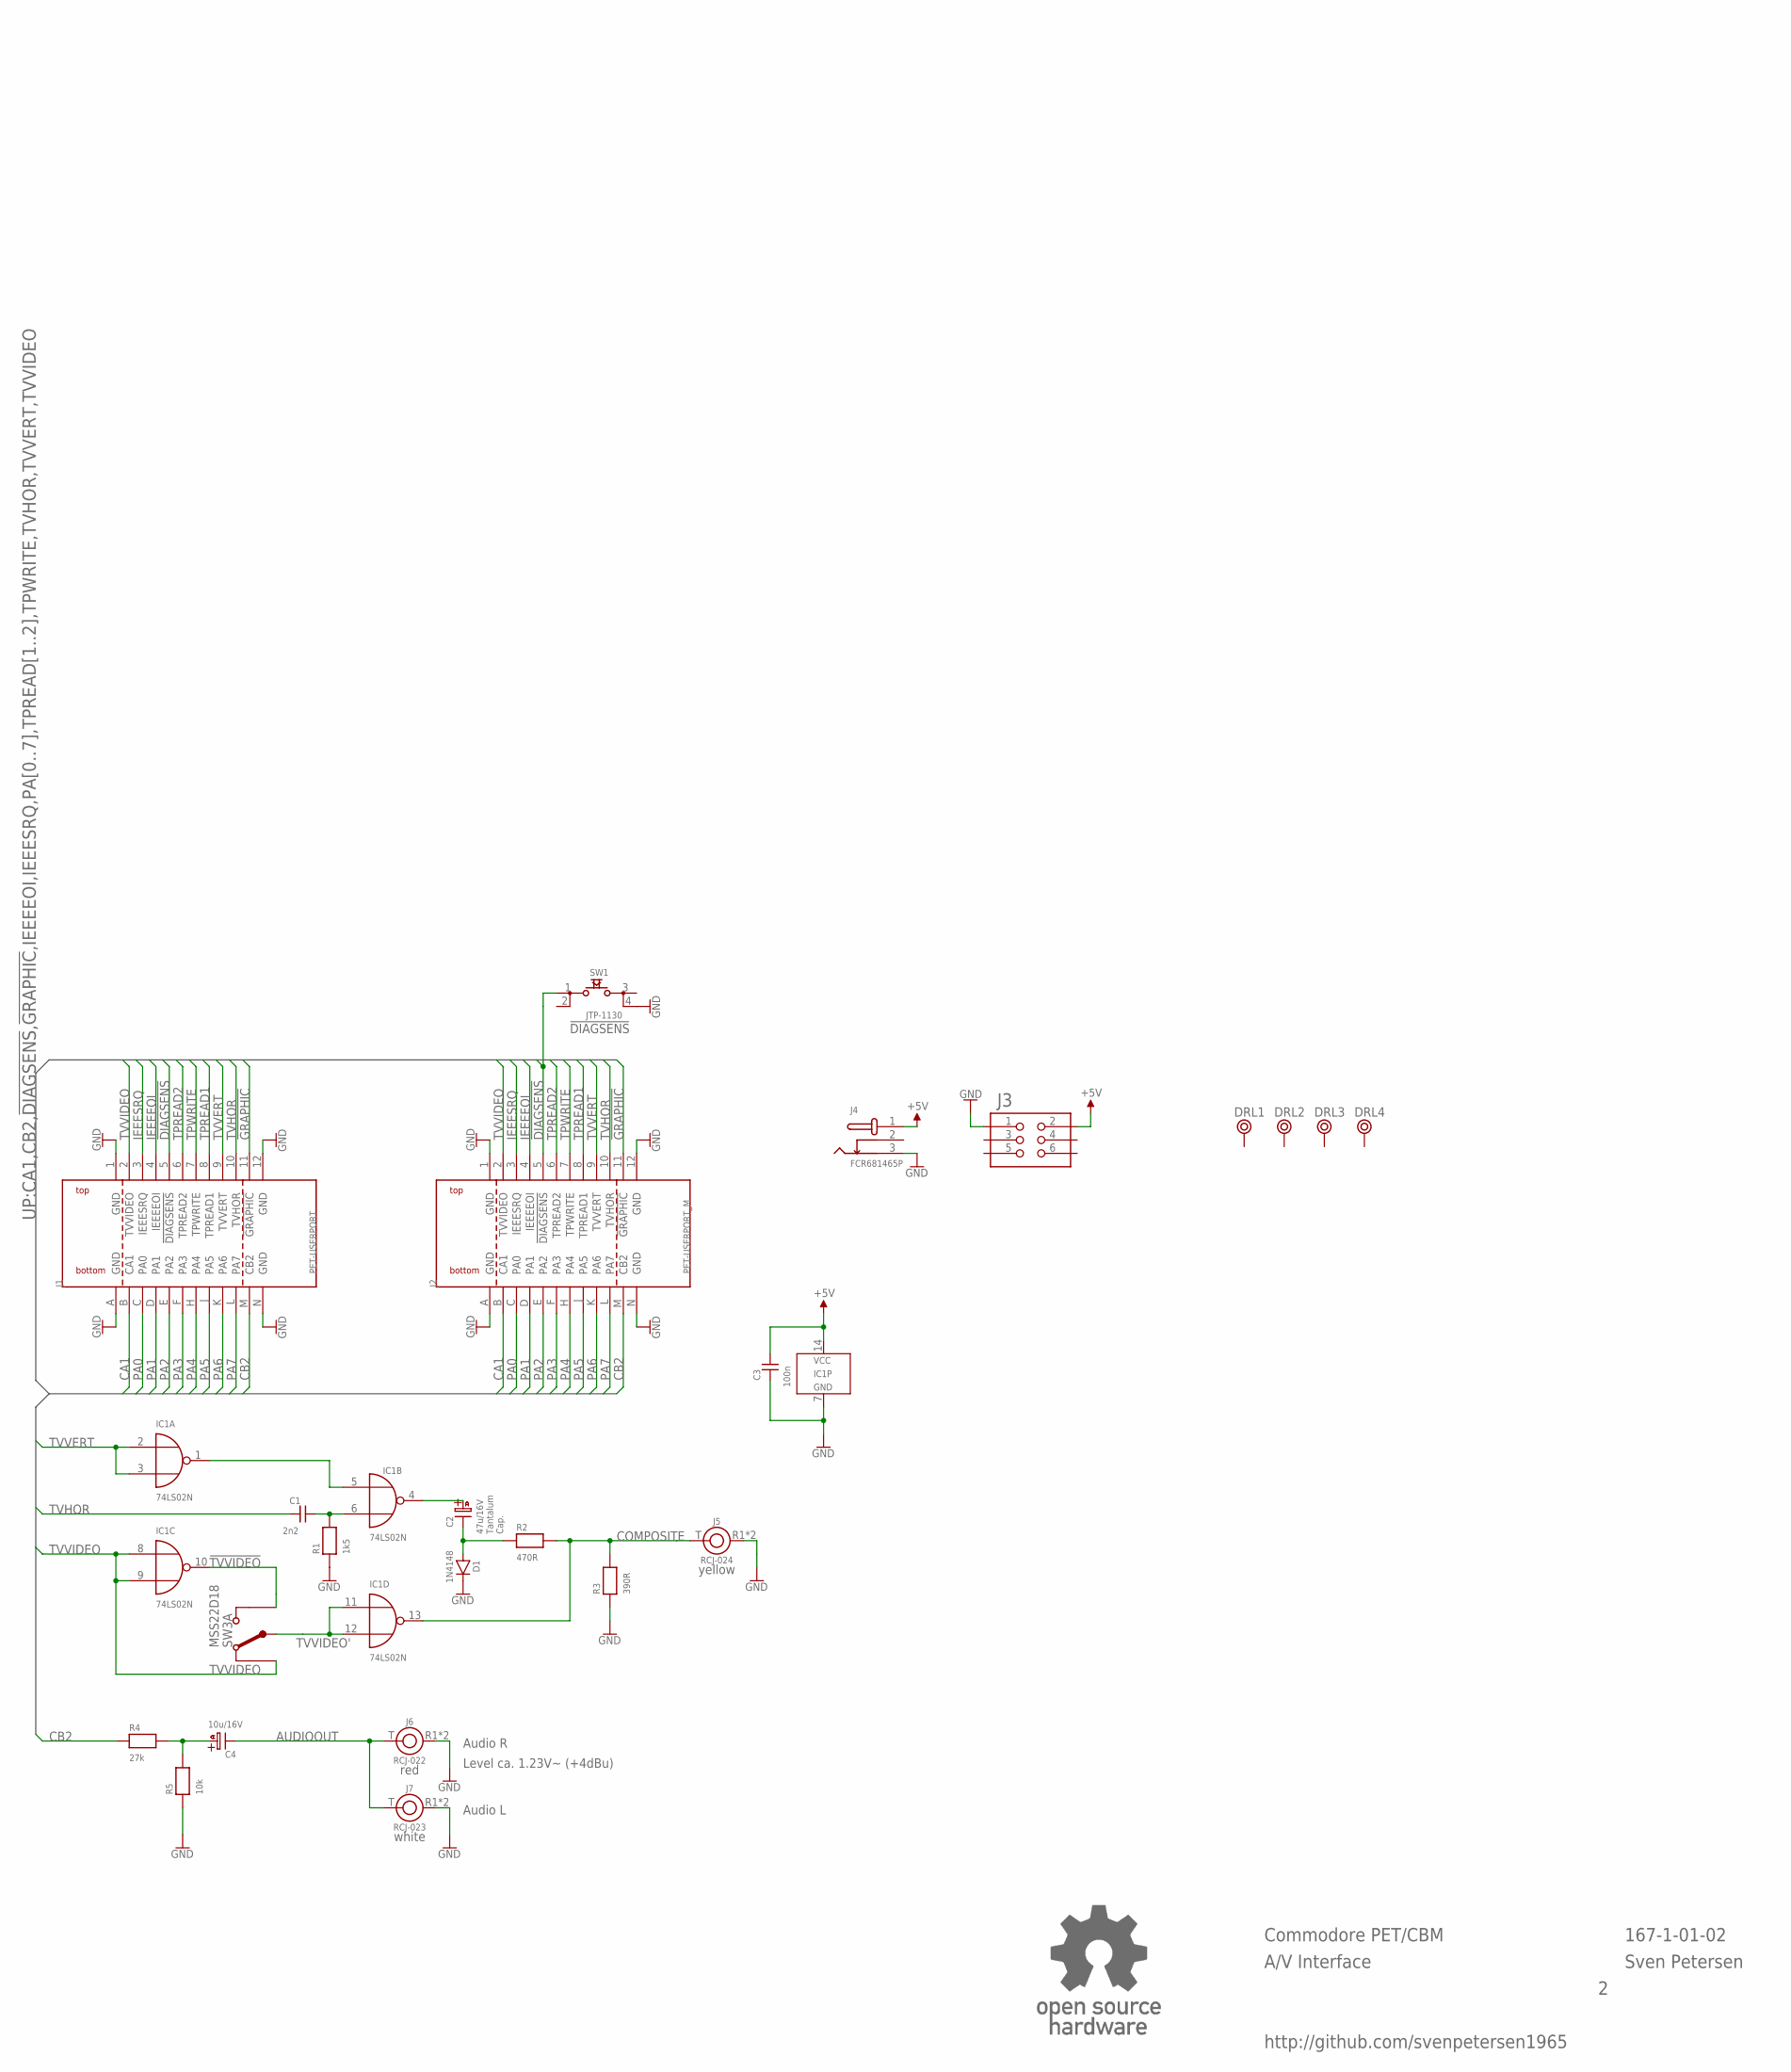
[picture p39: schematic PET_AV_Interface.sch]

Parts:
C1: 2n2; C-2,5
C2: 47u/16V; C5,0/2,0
C3: 100n; C-2,5
C4: 10u/16V; C5,0/2,0
D1: 1N4148; DO-35/3
DRL1, DRL2, DRL3, DRL4: BOHR3,5
IC1: 74LS02N; DIL-14
J1: PET-USERPORT; USERPORT
J2: PET-USERPORT_M; USERPORT_M
J3: 2X03WV
J4: FCR681465P
J5: RCJ-024; RCJ-02X
J6: RCJ-022; RCJ-02X
J7: RCJ-023; RCJ-02X
R1: 1k5; R-10
R2: 470R; R-10
R3: 390R; R-10
R4: 27k; R-10
R5: 10k; R-10
SW1: JTP-1130
SW3: MSS22D18; DPDT_9MM
U$2: OPEN_SOURCE_HW; OPENHW

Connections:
!DIAGSENS: J1.5 (!DIAGSENS), J2.5 (!DIAGSENS), SW1.1
!GRAPHIC: J1.11 (!GRAPHIC), J2.11 (!GRAPHIC)
!TVVERT': IC1.1 (O), IC1.5 (I0)
!TVVIDEO: IC1.10 (O), SW3.1 (UP)
+5V: C3.2, IC1.14 (VCC), J3.2, J4.1
AUDIOOUT: C4.K (-), J6.T, J7.T
CA1: J1.B (CA1), J2.B (CA1)
CB2: J1.M (CB2), J2.M (CB2), R4.1
COMPOSITE: IC1.13 (O), J5.T, R2.2, R3.2
GND: C3.1, D1.K, IC1.7 (GND), J1.1 (GND), J1.12 (GND), J1.A (GND), J1.N (GND), J2.1 (GND), J2.12 (GND), J2.A (GND), J2.N (GND), J3.1, J4.3, J5.R1 (R), J5.R2 (R), J6.R1 (R), J6.R2 (R), J7.R1 (R), J7.R2 (R), R1.1, R3.1, R5.1, SW1.4
IEEEEOI: J1.4 (IEEEEOI), J2.4 (IEEEEOI)
IEEESRQ: J1.3 (IEEESRQ), J2.3 (IEEESRQ)
unnamed: C4.A (+), R4.2, R5.2
unnamed: C1.2, IC1.6 (I1), R1.2
unnamed: C2.A (+), IC1.4 (O)
unnamed: C2.K (-), D1.A, R2.1
PA0: J1.C (PA0), J2.C (PA0)
PA1: J1.D (PA1), J2.D (PA1)
PA2: J1.E (PA2), J2.E (PA2)
PA3: J1.F (PA3), J2.F (PA3)
PA4: J1.H (PA4), J2.H (PA4)
PA5: J1.J (PA5), J2.J (PA5)
PA6: J1.K (PA6), J2.K (PA6)
PA7: J1.L (PA7), J2.L (PA7)
TPREAD1: J1.8 (TPREAD1), J2.8 (TPREAD1)
TPREAD2: J1.6 (TPREAD2), J2.6 (TPREAD2)
TPWRITE: J1.7 (TPWRITE), J2.7 (TPWRITE)
TVHOR: C1.1, J1.10 (TVHOR), J2.10 (TVHOR)
TVVERT: IC1.2 (I0), IC1.3 (I1), J1.9 (TVVERT), J2.9 (TVVERT)
TVVIDEO: IC1.8 (I0), IC1.9 (I1), J1.2 (TVVIDEO), J2.2 (TVVIDEO), SW3.3 (DWN)
TVVIDEO': IC1.11 (I0), IC1.12 (I1), SW3.2 (COM)

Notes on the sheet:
http://github.com/svenpetersen1965
Commodore PET/CBM
A/V Interface
Sven Petersen
167-1-01-02
yellow
red
white
Audio R
Audio L
Level ca. 1.23V~ (+4dBu)
Tantalum Cap.

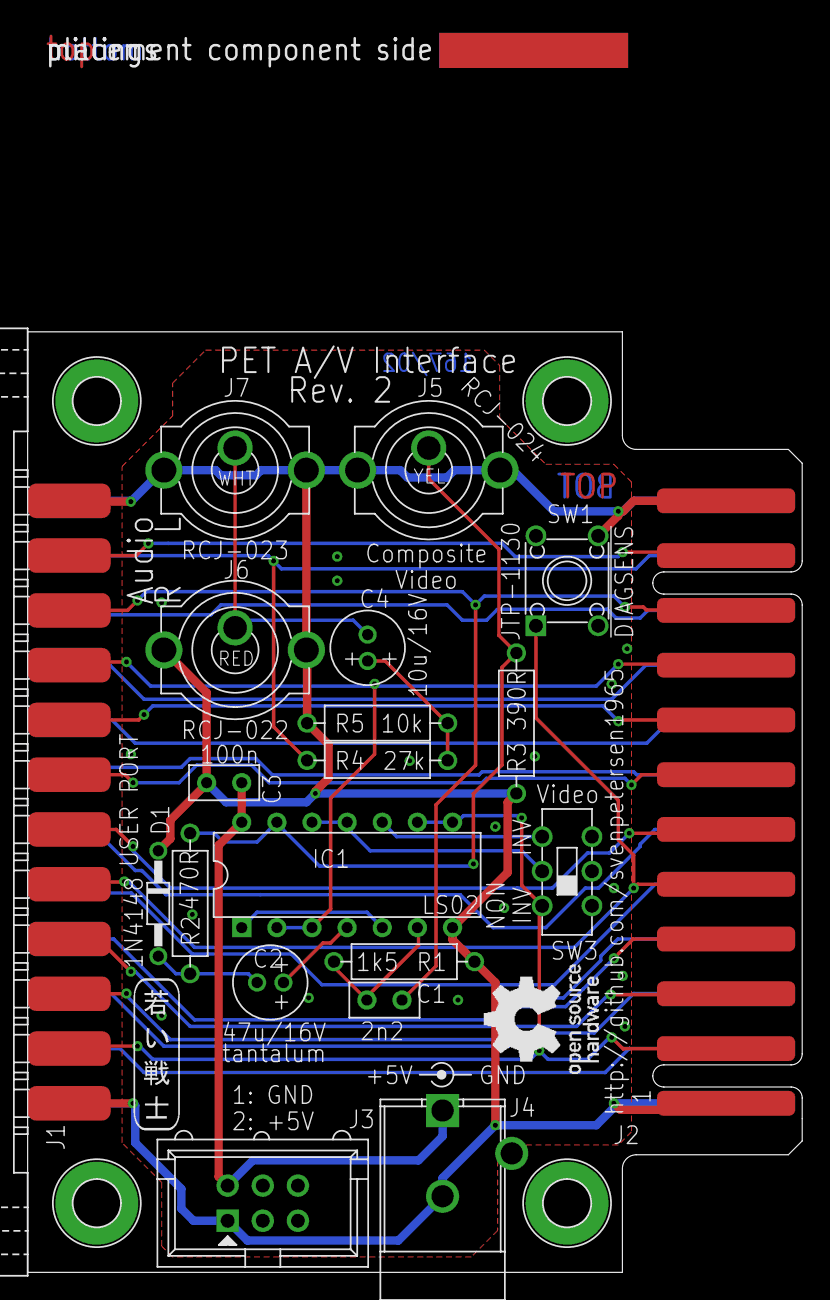
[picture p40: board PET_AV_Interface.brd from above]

Board: 2 copper layers, 56.0 x 68.0 mm, 28 parts (0 on the bottom side), 31 nets.

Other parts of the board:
U$22: PCB-TITLE/
U$23: 2LAYER
U$26: SVEN_TAG

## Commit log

2024-07-19 Release of Rev. 2
    [Label_BarrelPwr.dxf, Label_CPPwr.dxf, PETAV_BOM_2_0.xlsx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]
2024-07-29 Fusion360 files uploaded
    [PET_AV-Interface_rev2 v11.f3d, PET_AV-Interface_rev2_barrel v10.f3d]
